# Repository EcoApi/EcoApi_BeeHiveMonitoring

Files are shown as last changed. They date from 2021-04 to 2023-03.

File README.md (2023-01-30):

# EcoApi Bee hive monitoring

description TBD

## Features

- External i2c sensor (ex: as6200, si7021, shtxx, ...)
- Microphone analog with max9814 (FFT with dma)
- Microphone i2s (FFT with dma)
- Weight with load scale using hx711 (opimized for 3.3V with noise filter), calibration by led information
- CPU STM32F411CEU6
- Motion detection using mercure tilt vibration sensor
- Internal i2c sensor (ex: bmp180, bme180, bme280, ...)
- Lora using rfm95w 
- Powered battery like : Li-ion, Li-po, 3xNimh, 4xNimh, LifePO4, Alkaline 3x1.5 / 2x1.5, Li-SOCL2, Li-Mn02, 18650
- Reverse battery protection
- USB charger
- Ultra low power in sleep mode (wakeup by external rtc) ~2µA
- Power in running mode TBD
- USB cdc from stm32
- Power switch for internal / external VCC (3.3V)
- Fram
- EEprom
- Flash SPI
- External nano watchdog
- Debug by led, Uart, 

## Hardware

### Characteristics

- Cpu
- Lora
- Consumption
- Fram
- EEprom
- Flash
- Rtc
- WDG
- HX711
- Protection battery
- Backup capacitor explanation
- Battery charger
- USB cdc
- Ldo
- Buck-boost
- Power Load switch
- Wakeup parts (button, wdg, motion, rtc)
- Dip switch
- Connector (load cell, external sensors, Battery, internal sensor, Debug & SWD)
- Push button
- Debug (Uart, USB CDC, SWD)
- ....

### Pcb

Front
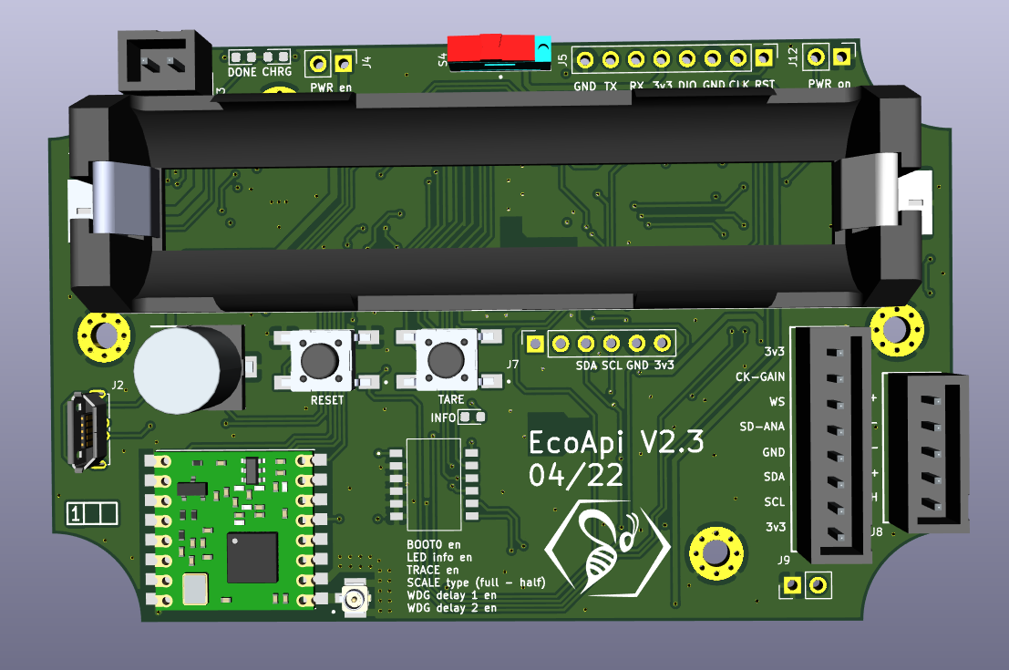
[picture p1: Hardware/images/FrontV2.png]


Back
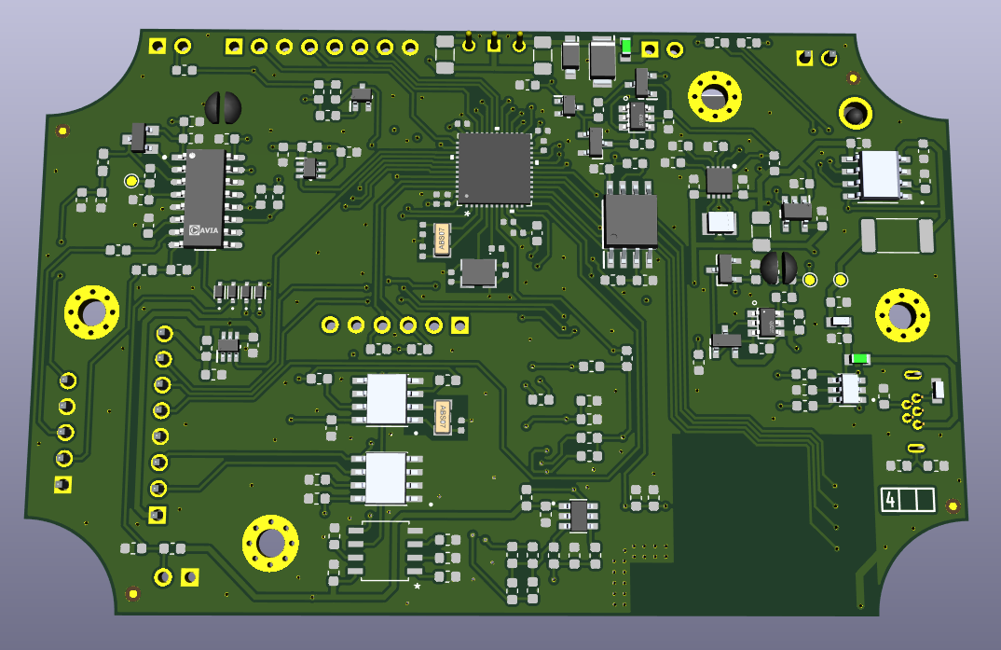
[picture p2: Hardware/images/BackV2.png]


### Pinout

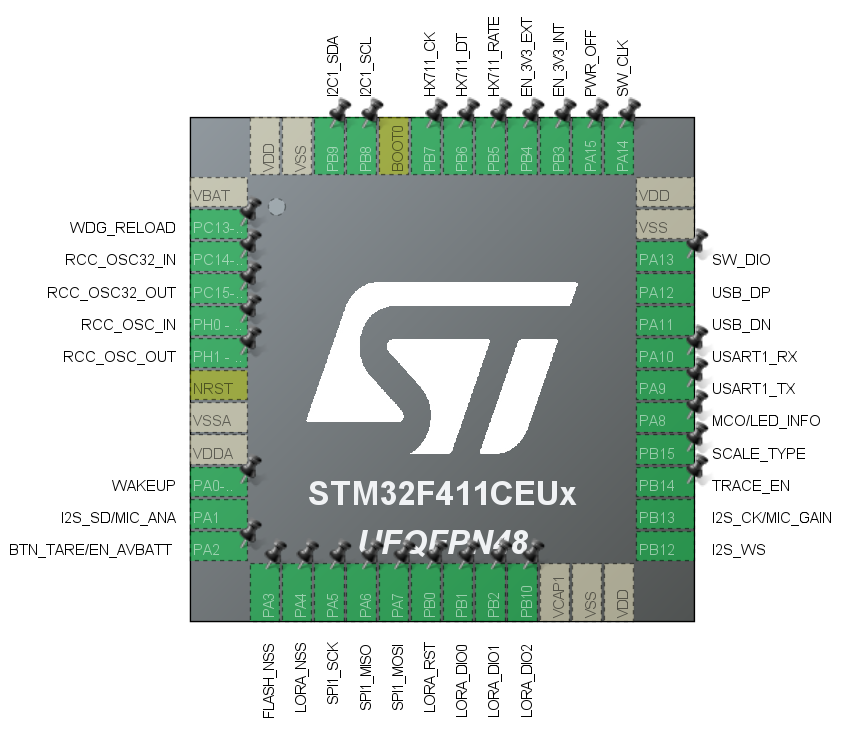
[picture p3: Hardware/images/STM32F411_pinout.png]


array of pins description

### pcb

describ options with 0R resistors. etc ...

#### JlcPcb production

- Bom and pick&place : https://support.jlcpcb.com/article/153-how-to-generate-bom-and-centroid-files-from-kicad-in-linux
- JlcPcb gerber files : https://support.jlcpcb.com/article/149-how-to-generate-gerber-and-drill-files-in-kicad

## Software

To be define (flow chart) ...

### Description

- Lora : ttn, webhook for beep, js decoder, frame format
- sensor template
- Sensors auto-detection
- Outside informations (temperature, pressure, humidity, wind, ...)
- Inside informations (Sound, temperature, humidity, gas, bee counter, custom sensor ...)
- System information (RSSI, VBATT, 
- describe directive in platforio.ini
- FFT on analog mic or I2S mic (parameters, range etc ...)
- sleep mode

### Ide & compilation

- pio
- plugins
- ....

### lmic debug ###

in platformio.ini

(1) uncomment :
	-D LMIC_DEBUG_LEVEL=2
	-D LMIC_ENABLE_event_logging=1
	-D LMIC_X_DEBUG_LEVEL=1

(2) replace in lmic/lmic.h :

#  ifdef LMIC_DEBUG_PRINTF_FN
#    define LMIC_X_DEBUG_PRINTF(f, ...) LMIC_DEBUG_PRINTF_FN(f, ## __VA_ARGS__)
#  else
#    error "LMIC_DEBUG_PRINTF_FN must be defined for LMIC_X_DEBUG_LEVEL > 0."
#  endif

by :

#define LMIC_X_DEBUG_PRINTF(f, ...) LMIC_DEBUG_PRINTF(f, ## __VA_ARGS__)

## how to

- Scale full or half
- Tare button
- Led information
- Motion tilt
- Debug
- usb charger leds
- Sleep on VBATT or 3.3V with slide switch
- Dip switch
- USB with android application (flutter.io or other)

## other 
[Editor.md](https://pandao.github.io/editor.md/en.html "Editor.md")

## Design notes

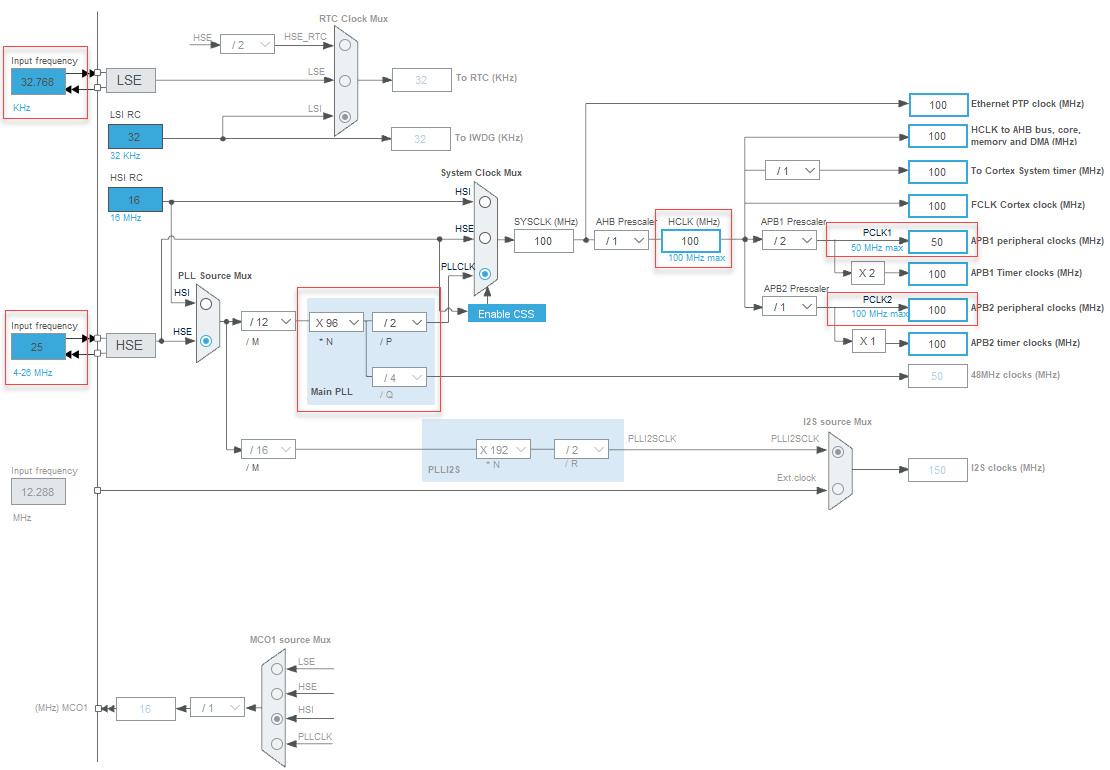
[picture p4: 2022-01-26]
Hardware/images/ide_hse_clock.png

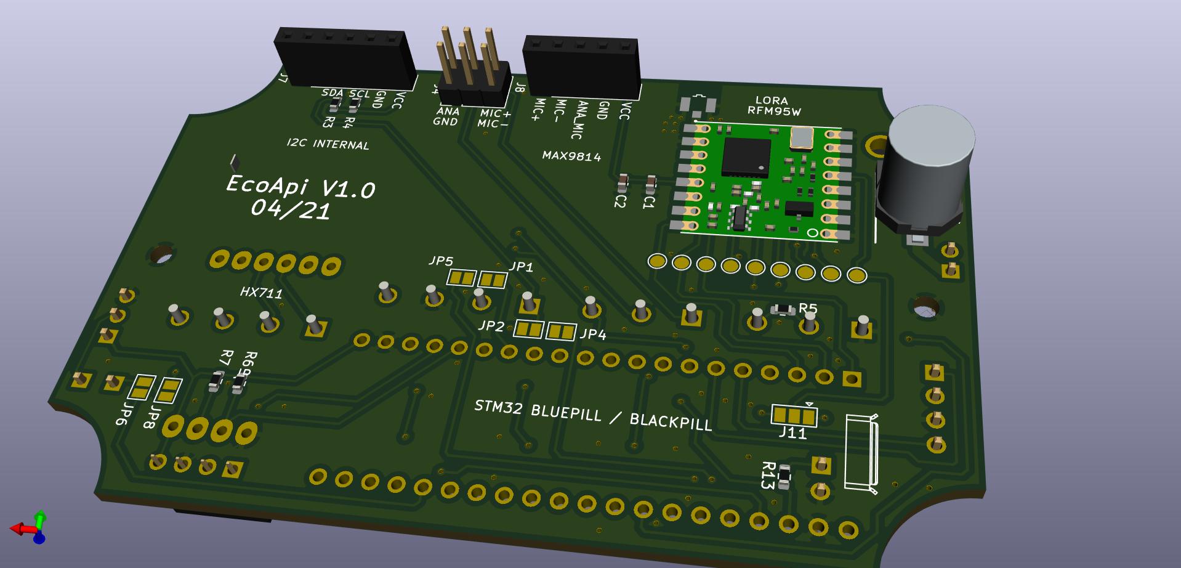
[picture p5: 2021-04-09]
Hardware/images/EcoApi_pcb3.jpg

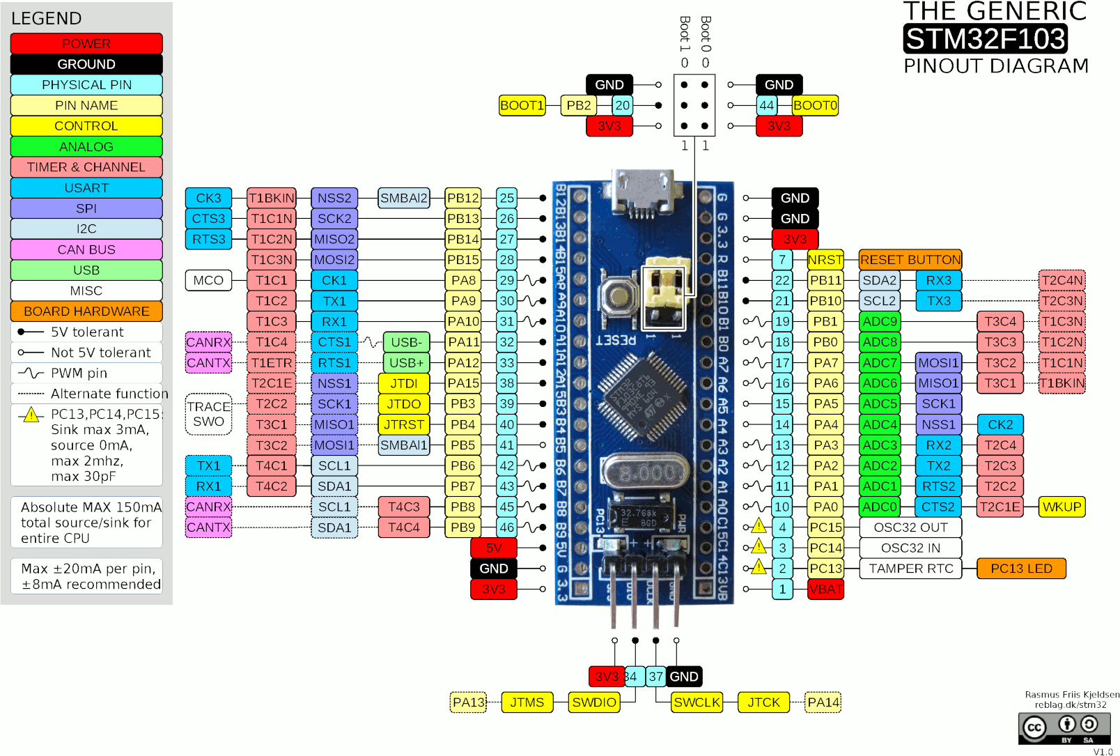
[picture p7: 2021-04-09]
Hardware/images/bluepill-pins.png

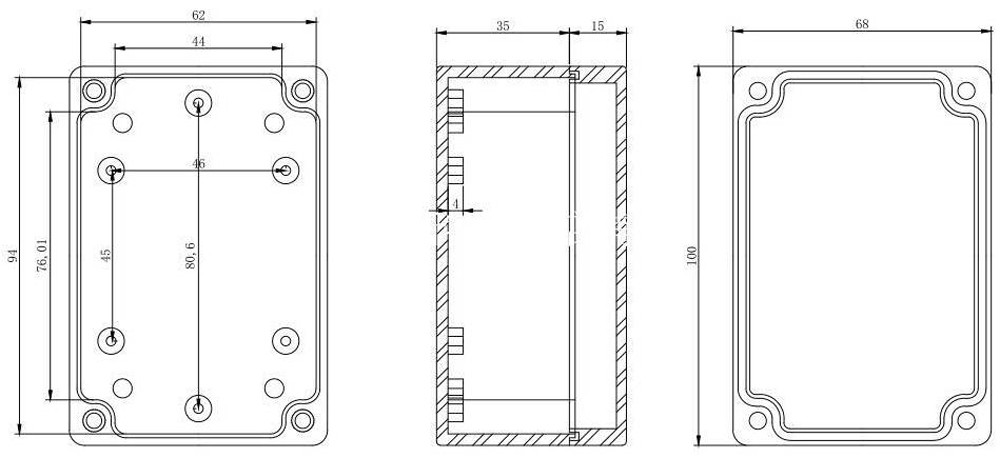
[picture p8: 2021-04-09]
Hardware/images/boitier.jpg

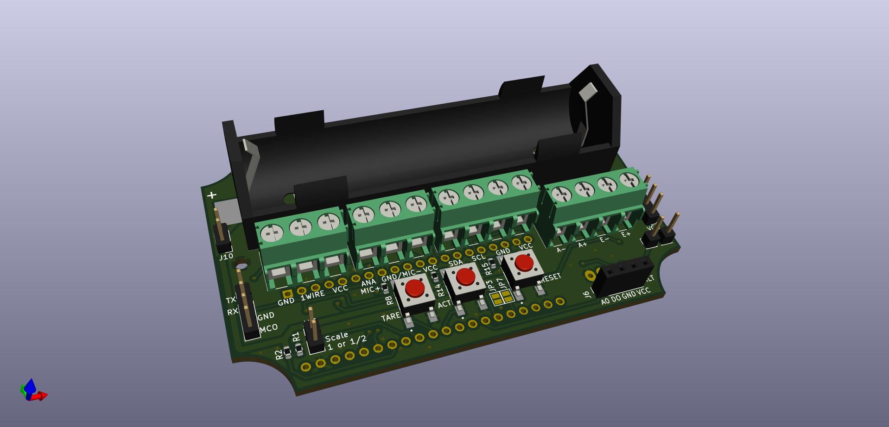
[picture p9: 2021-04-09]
Hardware/images/EcoApi_pcb2.jpg

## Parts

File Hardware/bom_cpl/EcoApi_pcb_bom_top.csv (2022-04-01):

Comment | Designator | Footprint | LCSC Part #
RFM95W-868S2 | U5
UFL | J1
1000uF | C18
POWER ON | J4 J12
18650_HOLDER | BT1
RED | D1
GREEN | D2
B2B-XH-A | J3
614105150721 | J2
I2C INTERNAL | J7
TARE | S1
RESET | S3
BLUE | D7
DSHP06TSGET | S2
B5B-XH-A__LF__SN_ | J8
B8B-XH-A_LF__SN_ | J9
TILT | J10
MSS-102559-14A-D | S4
Debug | J5

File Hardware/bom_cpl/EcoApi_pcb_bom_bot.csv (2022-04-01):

Comment | Designator | Footprint | LCSC Part #
0.1uF | C8 C7 C5 C6 C10 C11 C14 C15 C13 C2 C25 C22 C29 C44 C30 C31 C32 | 0603 | C1591
10uF | C9 C4 C12 C16 C21 | 0603 | C19702
4.7K | R26 R28 R29 R32 | 0603 | C23162
HX711 | U2 | SOP-16 | C43656
100R | R4 R5 | 0603 | C54021
20K | R22 | 0603 | C4184
22K | R21 | 0603 | C31850
3.3uH | L1 | 0603 | C21189
MB85RC04VPNF-G-JNERE1 | U4 | SOIC-8 | C8738
24LC02BT-I/SN | U7 | SOIC-8 | C5453
W25Q32JVSS | U6 | SOP-8 | C82344
0R | R20 R19 R18 R31 R8 R54 R55 R12 R13 R11 R25 | 0603 | NM_C21189
0R | R30 R33 R27 R24 R1 R17 R7 R49 R63 | 0603 | C21189
221K | R6 | 0603 | C22894
287K | R9 | 0603 | C22972
182K | R2 | 0603 | C22894
187K | R3 | 0603 | C22896
MMBT4403 | Q1 | SOT-23-3 | C85183
PCF8563T_5,518 | IC1 | SOIC-8 | C7440
TPL5010DDCR | U1 | SOT-23-6 | C473912
32.768kHz 12.5pF | Y1 | 3215 | C97606
22pF | C1 | 0402 | C76960
10K | R16 R58 R39 R68 R73 R67 R71 R69 | 0603 | C25804
TPS63900DSKR | U10
10uF | C23 | 0603 | NM_C19702
22uF | C24 | 0603 | NM_C59461
36.5K | R52 | 0603 | NM_C51261_
TP4056X | U8 | SOP-8 | C2763448
1K | R37 R36 R72 | 0603 | C21190
0.5R | R35 | 2512 | C27777
100K | R50 R44 R38 R23 | 0603 | C25803
IRLML6244TRPBF | Q3 Q6 | SOT-23-3 | C143946
1M | R47 R48 R53 R34 R51 R65 R42 R15 R45 | 0603 | C22935
10nF | C19 C46 | 0603 | C100042
4.7uF | C20 C17 | 0603 | C19666
22R | R40 R41 | 0603 | C23345
BLM18PG221SN1D | FB2 FB1 | 0603 | C80165
MF-FSMF050X-2 | F1 F2 | 0603 | C210357
FDC638P | Q2 Q7 | SSOT-6
1N4148WT | D6 D4 D5 D3 | SOD-523 | C232841
2.2uH | L2 | 0603
SIP32431DR3-T1GE3 | IC2 IC3 | SC-70-6 | C141606
BSS138 | Q5 Q4 | SOT-323-3 | C24553
USBLC6-2SC6 | D8 | SOT-23-6 | C7519
1uF | C26 C28 C27 C45 | 0603 | C59782
0R | R10 R46 R56 | 1206 | NM_C17888
NCP161ASN330T1G | PS1 | SOT-23-5 | C892187
BSS84AK,215 | Q8 Q9 | SOT-23-3 | C127273
PMEG10020AELPX | D10 | SOD-128 | C503397
PMEG10010ELRX | D9 | SOD-123W | C179426
4.7uF | C39 C40 | 0402 | C77004
STM32F411CEU6 | U13 | UFQFPN-48 | C60420
0.1uF | C41 C42 C43 C38 | 0402 | C1525
1uF | C37 | 0402 | C307427
25mHz 9pF +-10ppm | Y3 | 3225 | C255920
8pF | C35 C36 | 0402 | C161335
787R | R75 | 0402 | C270582
32.768kHz 6pF | Y2 | 3215 | C2692145
6pF | C34 C33 | 0402 | C437443
600Ω@100MHz | L3 | 0603 | C133937

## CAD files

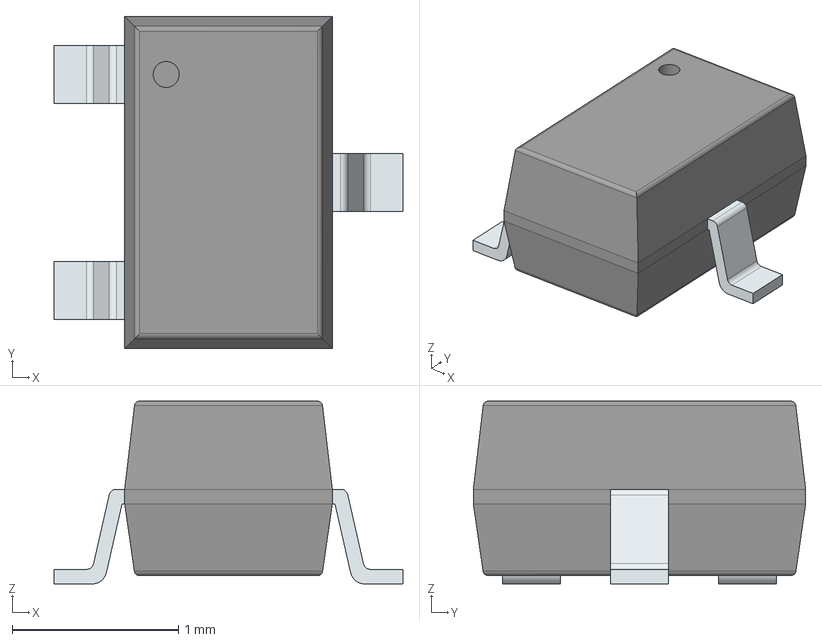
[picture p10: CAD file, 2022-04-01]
Hardware/lib_3d/BSS138PW,115.stp
2.10 x 2.00 x 1.10 mm
PinsArrayL
FilletPinR

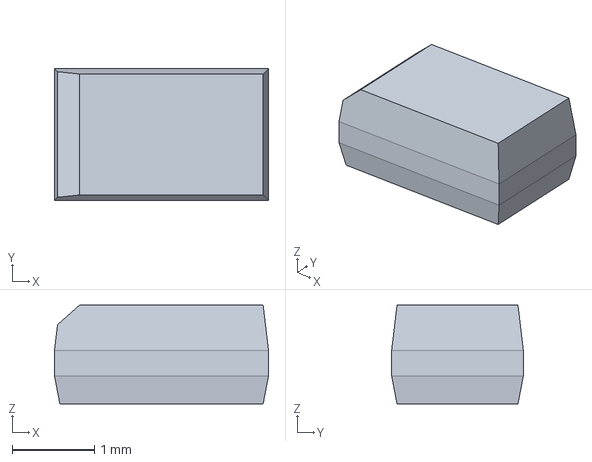
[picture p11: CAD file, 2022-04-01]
Hardware/lib_3d/BAT46WH,115.stp
2.60 x 1.60 x 1.20 mm

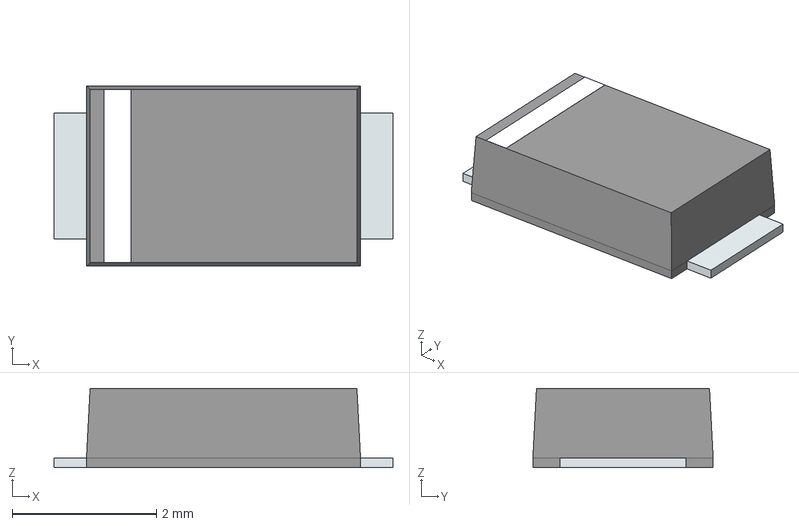
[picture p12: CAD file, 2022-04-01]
Hardware/lib_3d/PMEG10020AELPX.stp
4.70 x 2.50 x 1.10 mm
PinKIdent
PinK
PinA

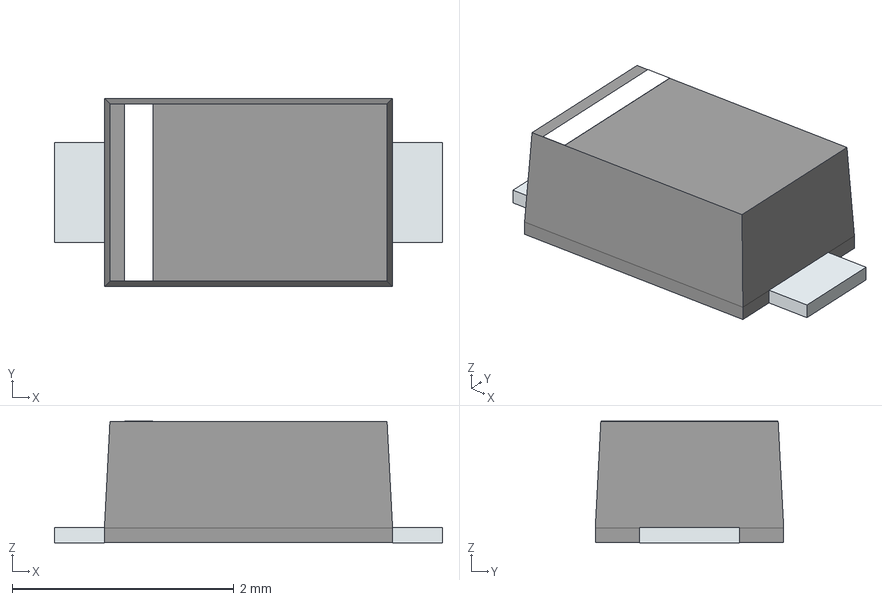
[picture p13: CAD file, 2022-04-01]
Hardware/lib_3d/PMEG10010ELRX.stp
3.50 x 1.70 x 1.10 mm
PinKIdent
PinK
PinA

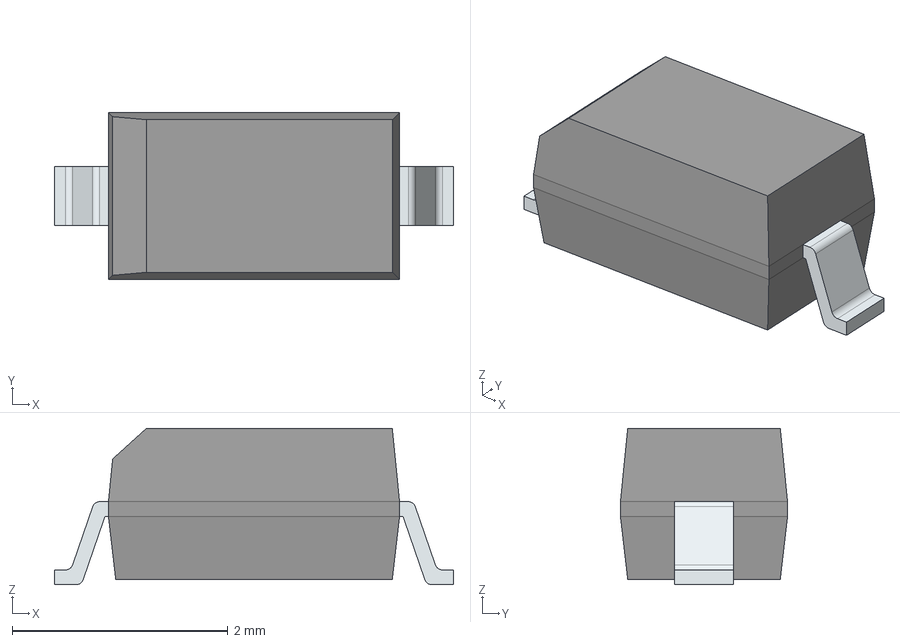
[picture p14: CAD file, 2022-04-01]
Hardware/lib_3d/BAT46W-7-F.stp
3.70 x 1.55 x 1.45 mm
FilletPinL
FilletPinR

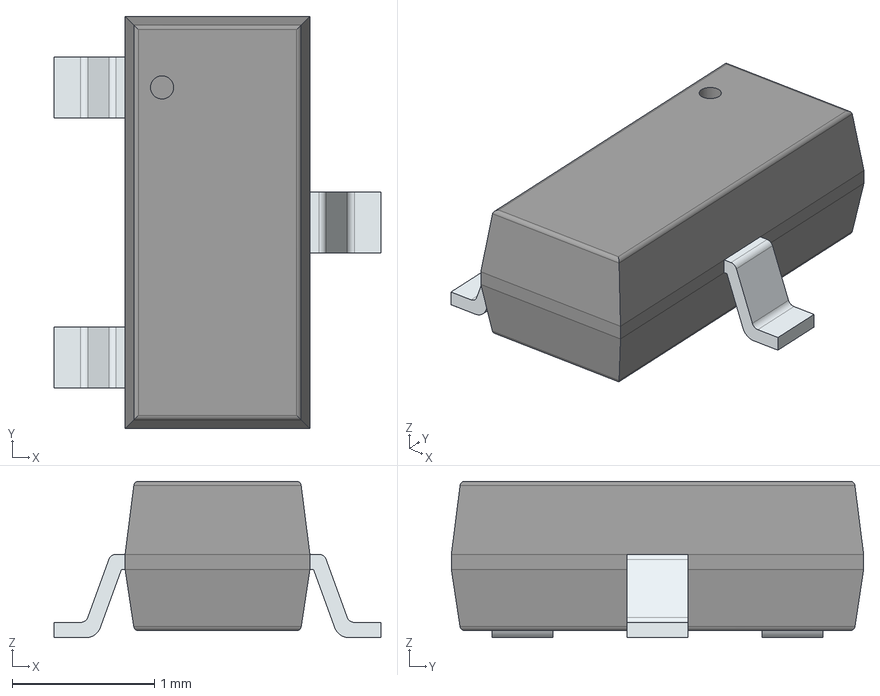
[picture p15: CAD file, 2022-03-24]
Hardware/lib_3d/BSS84AK,215.stp
2.30 x 2.90 x 1.10 mm
PinsArrayL
FilletPinR

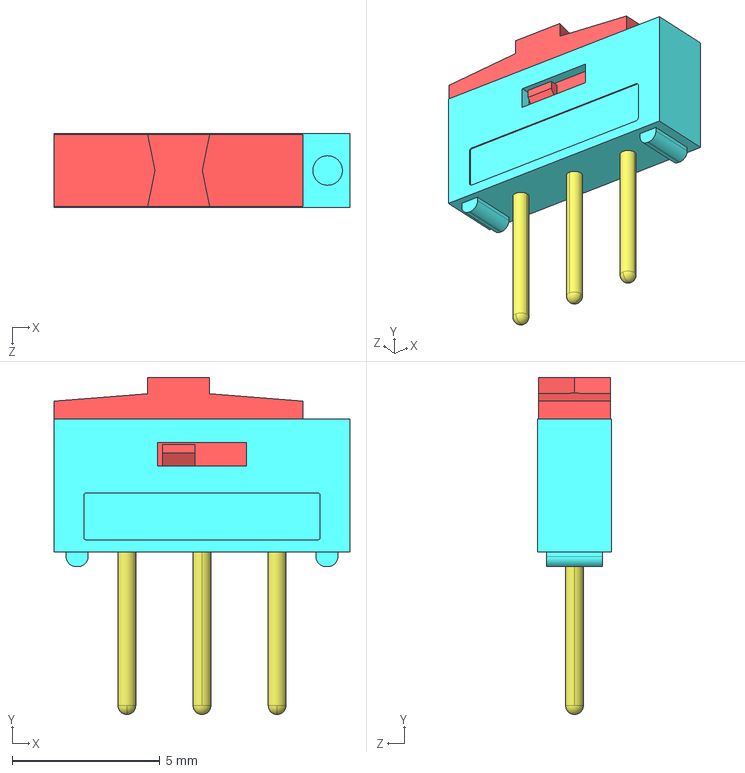
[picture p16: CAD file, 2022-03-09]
Hardware/lib_3d/MSS-102559-14A-D.step
10.0 x 11.4 x 2.50 mm

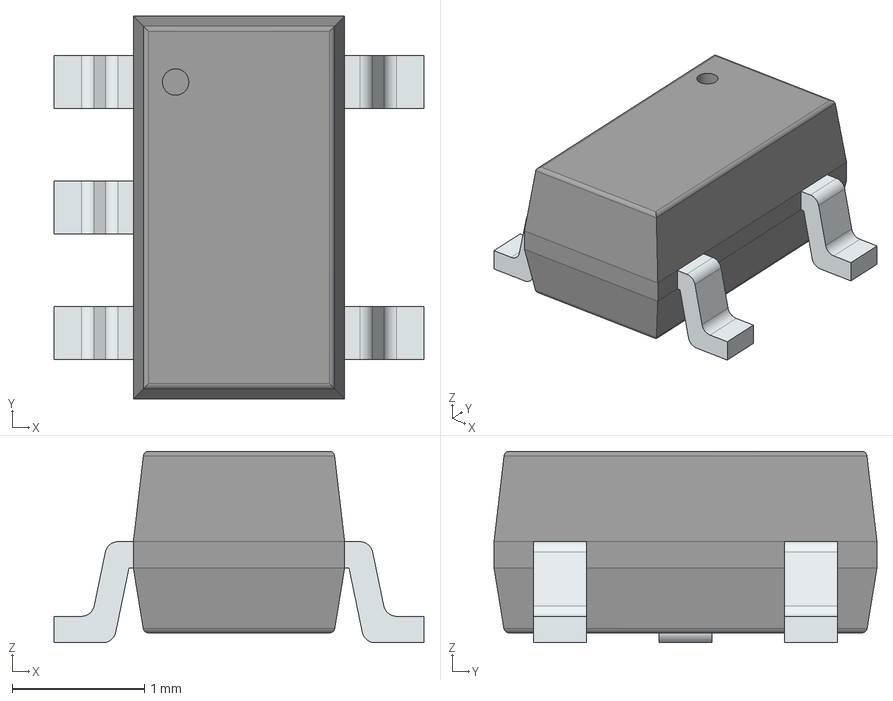
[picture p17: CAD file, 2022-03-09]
Hardware/lib_3d/NCP161ASN330T1G.stp
2.80 x 2.90 x 1.45 mm
PinsArrayL
PinsArrayR

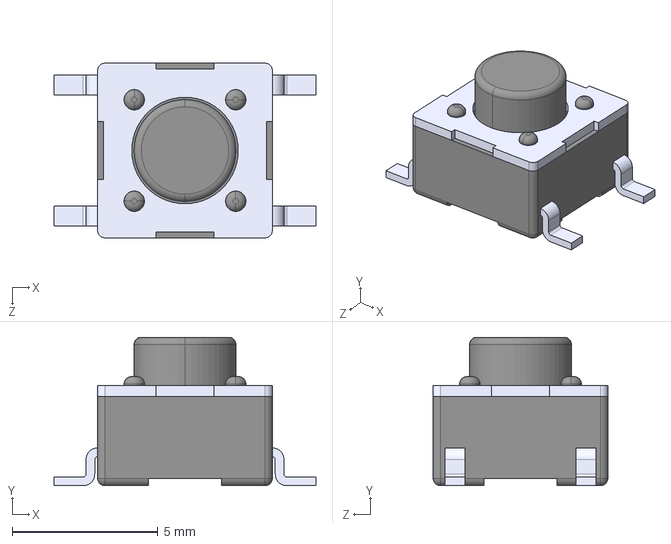
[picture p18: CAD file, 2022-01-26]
Hardware/lib_3d/PTS645SK50SMTR92LFS.STEP
9.00 x 5.10 x 6.00 mm

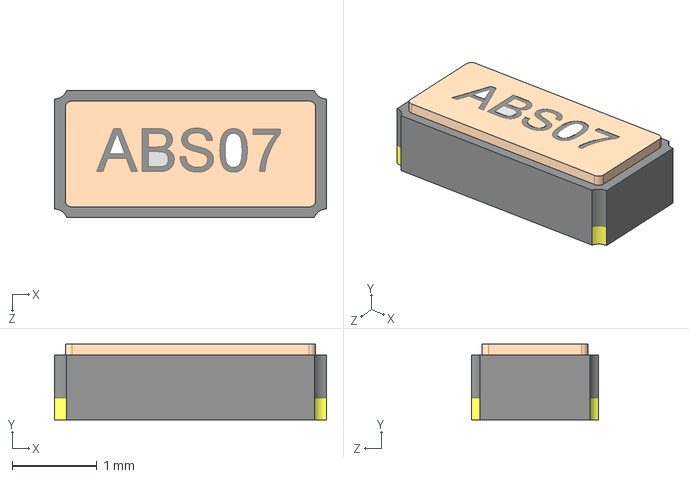
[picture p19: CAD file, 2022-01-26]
Hardware/lib_3d/ABS07-120-32.768KHZ-T.step
3.20 x 0.889 x 1.50 mm

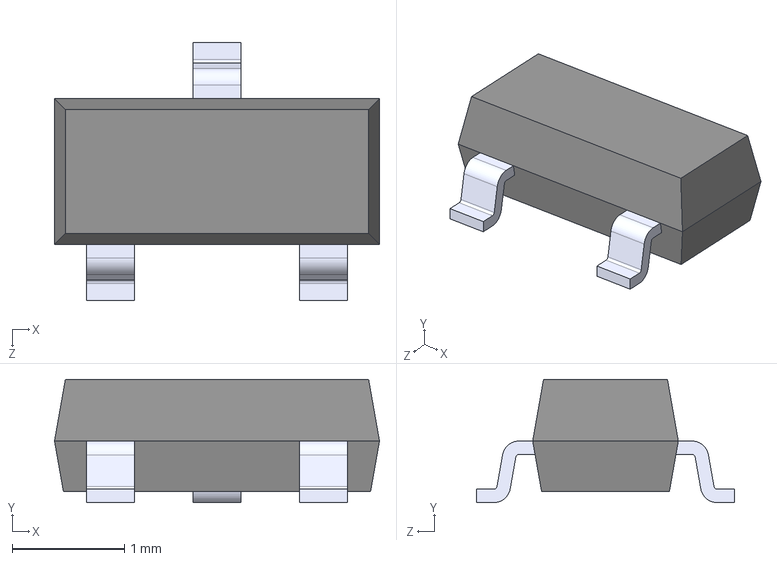
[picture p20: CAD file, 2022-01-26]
Hardware/lib_3d/BSS138.step
2.90 x 1.10 x 2.30 mm

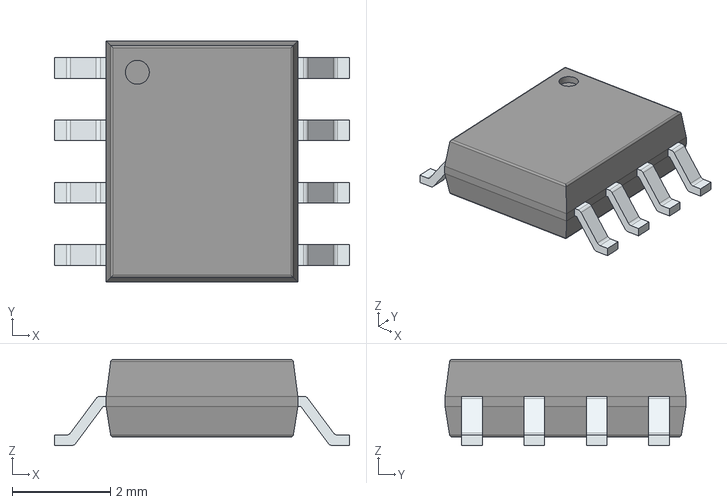
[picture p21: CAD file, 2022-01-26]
Hardware/lib_3d/PCF8563T_5,518.stp
6.00 x 4.90 x 1.75 mm
PinsArrayLR

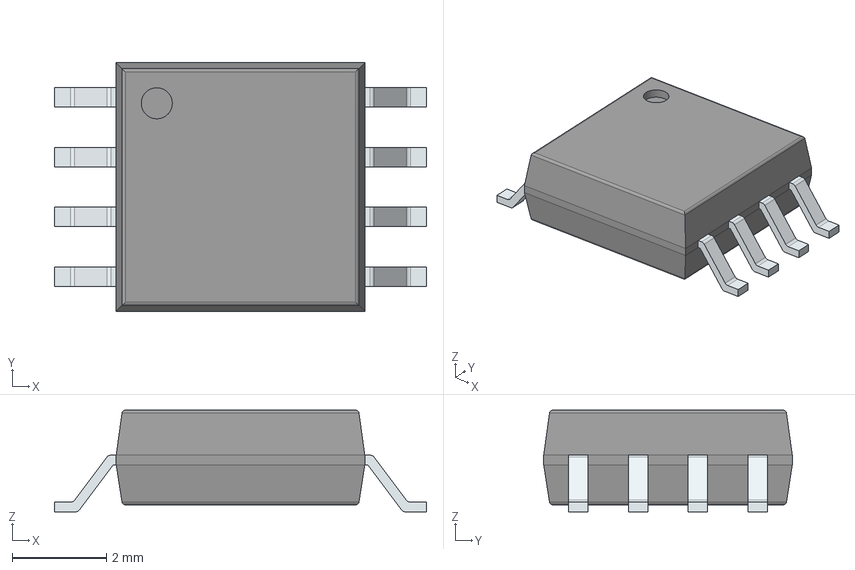
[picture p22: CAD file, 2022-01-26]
Hardware/lib_3d/W25Q32JVSSIQ_TR.stp
7.90 x 5.28 x 2.16 mm
PinsArrayLR

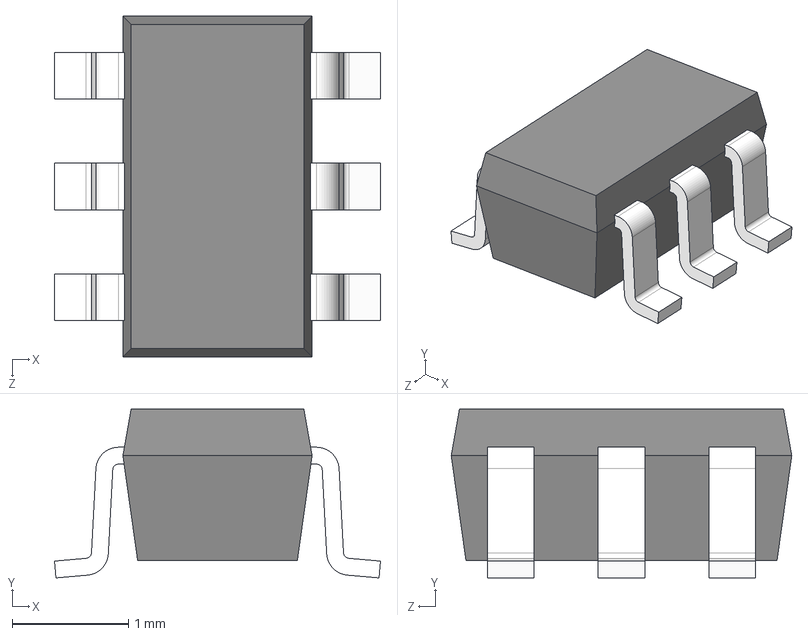
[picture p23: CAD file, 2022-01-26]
Hardware/lib_3d/USBLC6-2SC6.step
2.80 x 1.45 x 2.92 mm

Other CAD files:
Hardware/lib_3d/MMBT4403_.step
Hardware/lib_3d/BLM18PG221SN1D.step
Hardware/lib_3d/1042.step
Hardware/lib_3d/IRLML6244TRPBF.stp
Hardware/V1/lib_3d/EEE-FK0J102GP.stp
Hardware/V1/lib_3d/HX711.STEP
Hardware/V1/lib_3d/RFM9xW.step
Hardware/V1/lib_3d/U.FL-R-SMT_01_.step
Hardware/V1/lib_3d/UCD0J102MNL1GS.stp
Hardware/lib_3d/1N4148WT.step
Hardware/lib_3d/24LC02B_SN.step
Hardware/lib_3d/614105150721.stp
Hardware/lib_3d/Avia_Semiconductor_-_HX711.step
Hardware/lib_3d/B2B-XH-A.stp
Hardware/lib_3d/B5B-XH-A__LF__SN_.stp
Hardware/lib_3d/B8B-XH-A_LF__SN_.stp
Hardware/lib_3d/BLM18PG221SN1D.stp
Hardware/lib_3d/DFE252012P-2R2M_P2.step
Hardware/lib_3d/EEE-FK0J102GP.stp
Hardware/lib_3d/Fairchild_-_MMBT4403.step
Hardware/lib_3d/HX711.STEP
Hardware/lib_3d/IRLML6246TRPBF.step
Hardware/lib_3d/MF-FSMF050X-2.step
Hardware/lib_3d/MF-FSMF050X-2.stp
Hardware/lib_3d/ON_Semiconductor_-_FDC638P.step
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

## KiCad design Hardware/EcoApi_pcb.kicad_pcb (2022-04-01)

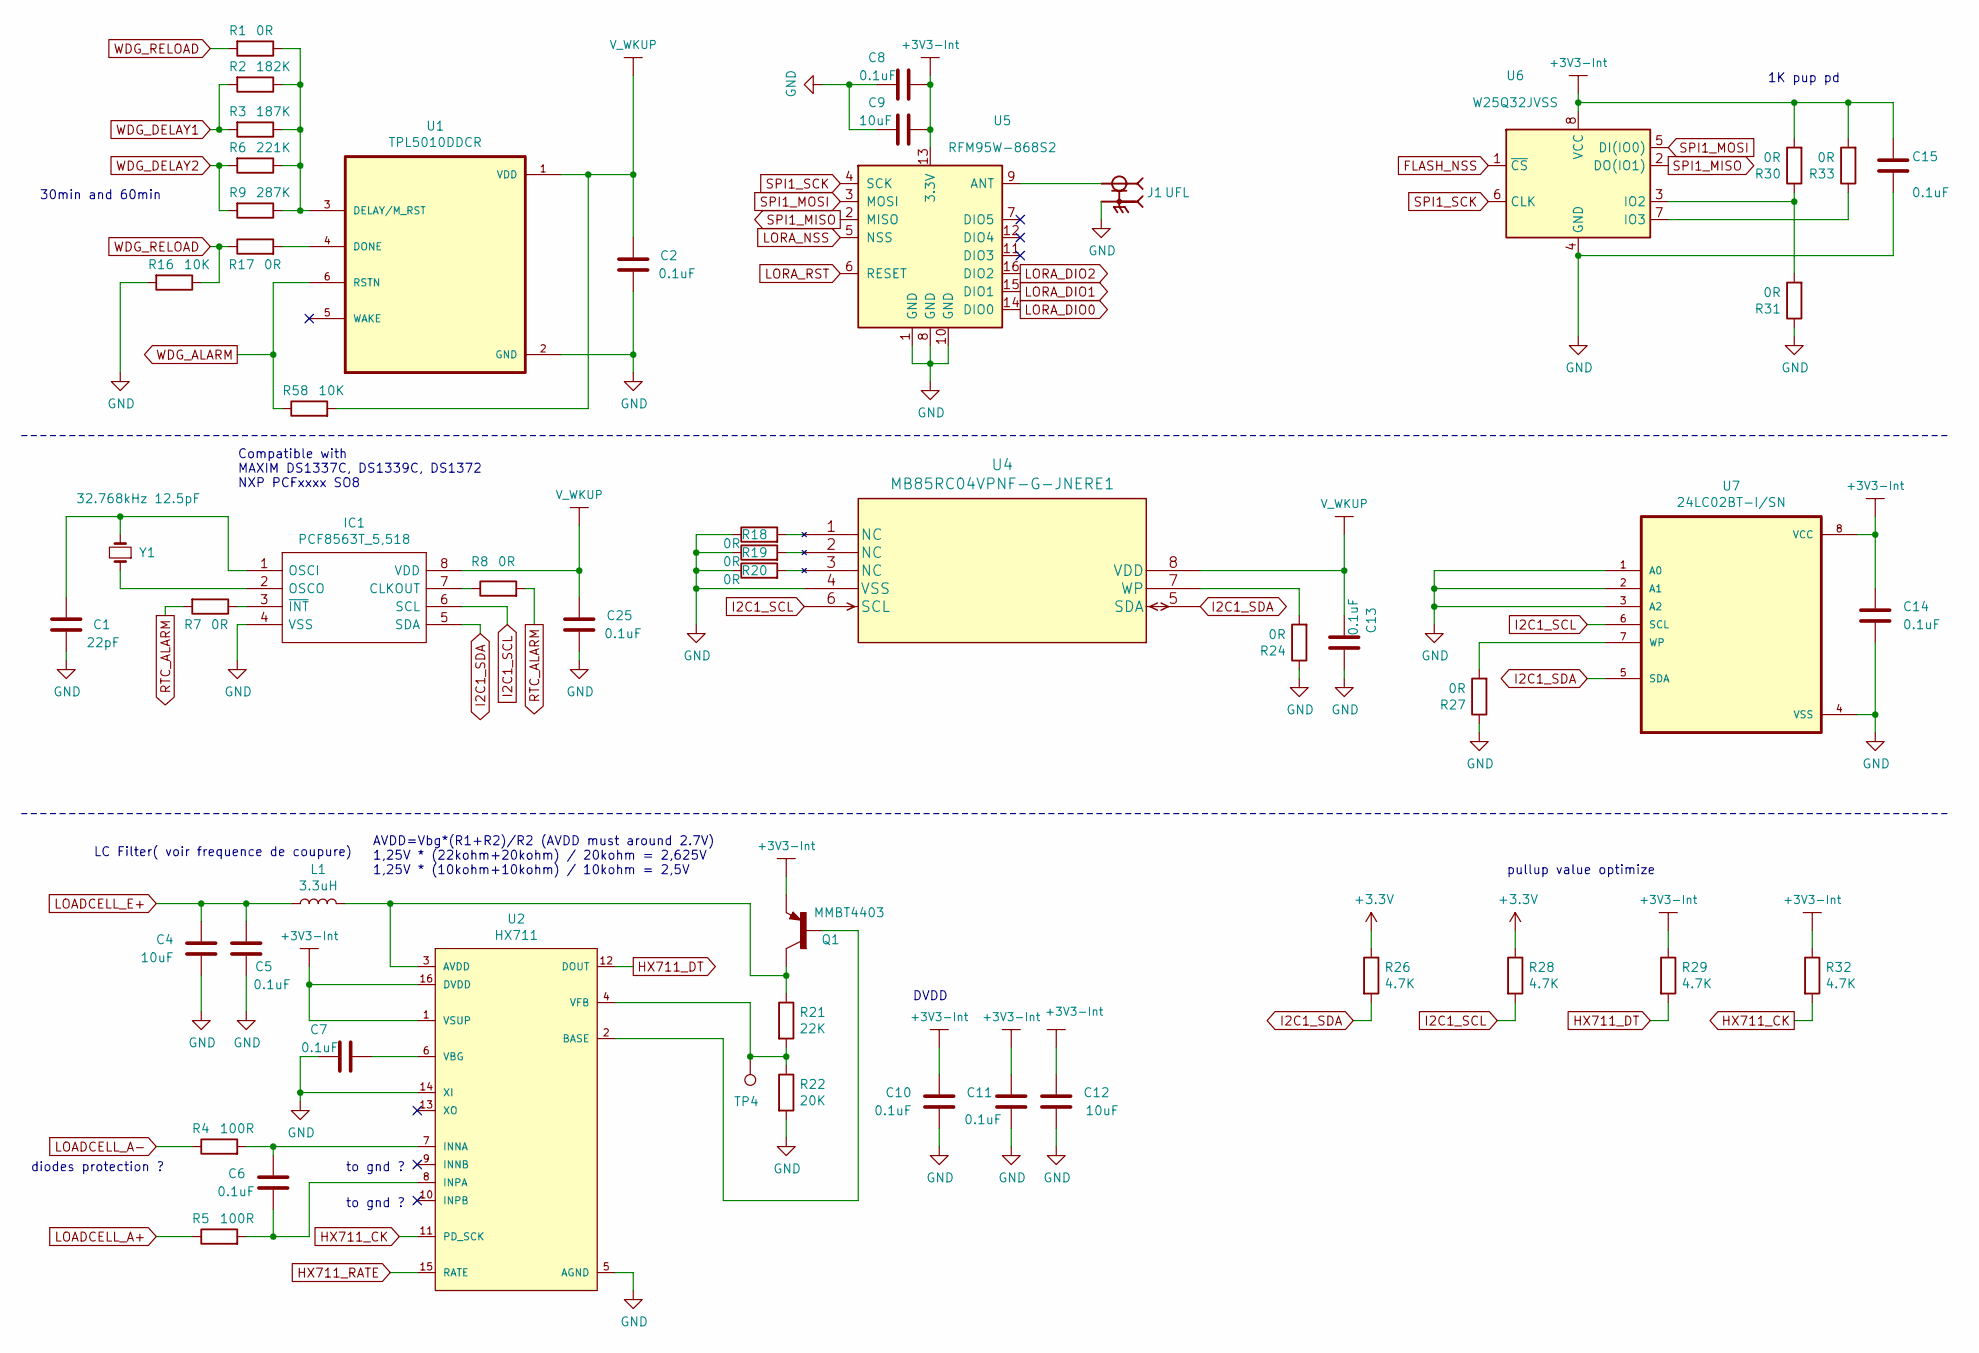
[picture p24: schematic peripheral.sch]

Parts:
C1: 22pF; C_0402_1005Metric; Tolerance 5%; Voltage 50V; Manufacturer_Part_Number GRM1555C1H220JA01D; JLC 0402
C2, C5, C6, C7, C8, C11, C13, C14, C15, C25: 0.1uF; C_0603_1608Metric; Tolerance 10%; Voltage 50V; Manufacturer_Part_Number CL10B104KB8NNNC; JLC 0603
C4: 10uF; C_0603_1608Metric; Voltage 10V; Tolerance 10%; Manufacturer_Part_Number CL10A106KP8NNNC; JLC 0603
C9, C12: 10uF; C_0603_1608Metric; Tolerance 10%; Voltage 10V; Manufacturer_Part_Number CL10A106KP8NNNC; JLC 0603
C10: 0.1uF; C_0603_1608Metric; Voltage 50V; Tolerance 10%; Manufacturer_Part_Number CL10B104KB8NNNC; JLC 0603
IC1: PCF8563T_5,518; SOIC127P600X175-8N; Manufacturer_Part_Number PCF8563T/5,518; Mouser Part Number 771-PCF8563T/5518
J1: UFL; IPEX_20279-001E-01; PARTREV 21
L1: 3.3uH; L_0603_1608Metric_Pad1.05x0.95mm_HandSolder; Manufacturer_Part_Number 0603WAF0000T5E; JLC 0603
Q1: MMBT4403; SOT23-BEC; Manufacturer_Part_Number MMBT4403-7-F; JLC SOT-23-3
R1, R7, R8, R17, R18, R19, R20, R24, R27, R30, R31, R33: 0R; R_0603_1608Metric; Tolerance 1%; Power Rating 1/10W; Manufacturer_Part_Number 0603WAF0000T5E; JLC 0603
R2: 182K; R_0603_1608Metric; Tolerance 1%; Power Rating 1/10W; Manufacturer_Part_Number 0603WAF1823T5E; JLC 0603
R3: 187K; R_0603_1608Metric; Tolerance 1%; Power Rating 1/10W; Manufacturer_Part_Number 0603WAF1873T5E; JLC 0603
R4, R5: 100R; R_0603_1608Metric; Tolerance 0.1%; Power Rating 1/16W; Manufacturer_Part_Number TC0325B1000T5E; JLC 0603
R6: 221K; R_0603_1608Metric; Tolerance 1%; Power Rating 1/10W; Manufacturer_Part_Number 0603WAF1823T5E; JLC 0603
R9: 287K; R_0603_1608Metric; Tolerance 1%; Power Rating 1/10W; Manufacturer_Part_Number 0603WAF2873T5E; JLC 0603
R16, R58: 10K; R_0603_1608Metric; Tolerance 1%; Power Rating 1/10W; Manufacturer_Part_Number 0603WAF1002T5E; JLC 0603
R21: 22K; R_0603_1608Metric; Tolerance 1%; Power Rating 1/10W; Manufacturer_Part_Number 0603WAF2202T5E; JLC 0603
R22: 20K; R_0603_1608Metric; Tolerance 1%; Power Rating 1/10W; Manufacturer_Part_Number 0603WAF2002T5E; JLC 0603
R26, R28, R29, R32: 4.7K; R_0603_1608Metric; Tolerance 1%; Power Rating 1/10W; Manufacturer_Part_Number 0603WAF4701T5E; JLC 0603
TP4: TestPoint; TestPoint_Pad_D1.0mm
U1: TPL5010DDCR; SOT95P280X110-6N; Manufacturer_Part_Number TPL5010DDCR; JLC SOT-23-6
U2: HX711; Avia_Semiconductor-HX711-IPC_A; Manufacturer_Part_Number HX711Copy; JLC SOP-16
U4: MB85RC04VPNF-G-JNERE1; MB85RC16PNF-G-JNE1; Manufacturer_Part_Number MB85RC04VPNF-G-JNERE1; JLC SOIC-8
U5: RFM95W-868S2; RFM95W
U6: W25Q32JVSS; SOIC127P790X216-8N; Manufacturer_Part_Number W25Q32JVSSIQ; JLC SOP-8
U7: 24LC02BT-I/SN; SOIC127P600X175-8N; Manufacturer_Part_Number 24LC02BT-I/SN; JLC SOIC-8
Y1: 32.768kHz 12.5pF; XTAL_ABS07-120-32.768KHZ-T; Manufacturer_Part_Number SC-32S32.768kHz20PPM12.5pF; JLC 3215

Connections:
+3V3_int: C8.1, C9.1, C10.1, C11.1, C12.1, C14.2, C15.2, Q1.E, R29.1, R30.2, R32.1, R33.2, U2.1 (VSUP), U2.16 (DVDD), U5.13 (3.3V), U6.8 (VCC), U7.8 (VCC); also elsewhere on the board
FLASH_NSS: U6.1 (~CS); also elsewhere on the board
GND: C1.2, C2.2, C4.2, C5.2, C7.2, C8.2, C9.2, C10.2, C11.2, C12.2, C13.1, C14.1, C15.1, C25.2, IC1.4 (VSS), J1.2, J1.3, R16.2, R18.1, R19.1, R20.1, R22.2, R24.1, R27.1, R31.1, U1.2 (GND), U2.5 (AGND), U2.14 (XI), U4.4 (VSS), U5.1 (GND), U5.8 (GND), U5.10 (GND), U6.4 (GND), U7.1 (A0), U7.2 (A1), U7.3 (A2), U7.4 (VSS); also elsewhere on the board
HX711_CK: R32.2, U2.11 (PD_SCK); also elsewhere on the board
HX711_DT: R29.2, U2.12 (DOUT); also elsewhere on the board
HX711_RATE: U2.15 (RATE); also elsewhere on the board
I2C1_SCL: IC1.6 (SCL), R28.2, U4.6 (SCL), U7.6 (SCL); also elsewhere on the board
I2C1_SDA: IC1.5 (SDA), R26.2, U4.5 (SDA), U7.5 (SDA); also elsewhere on the board
LOADCELL_A+: R5.1; also elsewhere on the board
LOADCELL_A-: R4.1; also elsewhere on the board
LOADCELL_E+: C4.1, C5.1, L1.1; also elsewhere on the board
LORA_DIO0: U5.14 (DIO0); also elsewhere on the board
LORA_DIO1: U5.15 (DIO1); also elsewhere on the board
LORA_DIO2: U5.16 (DIO2); also elsewhere on the board
LORA_NSS: U5.5 (NSS); also elsewhere on the board
LORA_RST: U5.6 (RESET); also elsewhere on the board
unnamed: C1.1, IC1.1 (OSCI), Y1.2
unnamed: C6.1, R4.2, U2.7 (INNA)
unnamed: C6.2, R5.2, U2.8 (INPA)
unnamed: C7.1, U2.6 (VBG)
unnamed: IC1.2 (OSCO), Y1.1
unnamed: IC1.3 (~INT), R7.1
unnamed: IC1.7 (CLKOUT), R8.1
unnamed: J1.1, U5.9 (ANT)
unnamed: L1.2, Q1.C, R21.1, U2.3 (AVDD)
unnamed: Q1.B, U2.2 (BASE)
unnamed: R1.1, R2.1, R3.1, R6.1, R9.1, U1.3 (DELAY/M_RST)
unnamed: R17.2, U1.4 (DONE)
unnamed: R18.2, U4.1 (NC)
unnamed: R19.2, U4.2 (NC)
unnamed: R20.2, U4.3 (NC)
unnamed: R21.2, R22.1, TP4.1, U2.4 (VFB)
unnamed: R24.2, U4.7 (WP)
unnamed: R27.2, U7.7 (WP)
unnamed: R30.1, R31.2, U6.3 (IO2)
unnamed: R33.1, U6.7 (IO3)
RTC_ALARM: R7.2, R8.2; also elsewhere on the board
SPI1_MISO: U5.2 (MISO), U6.2 (DO(IO1)); also elsewhere on the board
SPI1_MOSI: U5.3 (MOSI), U6.5 (DI(IO0)); also elsewhere on the board
SPI1_SCK: U5.4 (SCK), U6.6 (CLK); also elsewhere on the board
V_WKUP: C2.1, C13.2, C25.1, IC1.8 (VDD), R58.2, U1.1 (VDD), U4.8 (VDD); also elsewhere on the board
WDG_ALARM: R58.1, U1.6 (RSTN); also elsewhere on the board
WDG_DELAY1: R2.2, R3.2; also elsewhere on the board
WDG_DELAY2: R6.2, R9.2; also elsewhere on the board
WDG_RELOAD: R1.2, R16.1, R17.1; also elsewhere on the board

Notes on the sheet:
AVDD=Vbg*(R1+R2)/R2 (AVDD must around 2.7V) 1,25V * (22kohm+20kohm) / 20kohm = 2,625V 1,25V * (10kohm+10kohm) / 10kohm = 2,5V
diodes protection ?
DVDD
to gnd ?
LC Filter( voir frequence de coupure)
Compatible with MAXIM DS1337C, DS1339C, DS1372 NXP PCFxxxx SO8
30min and 60min
pullup value optimize
1K pup pd

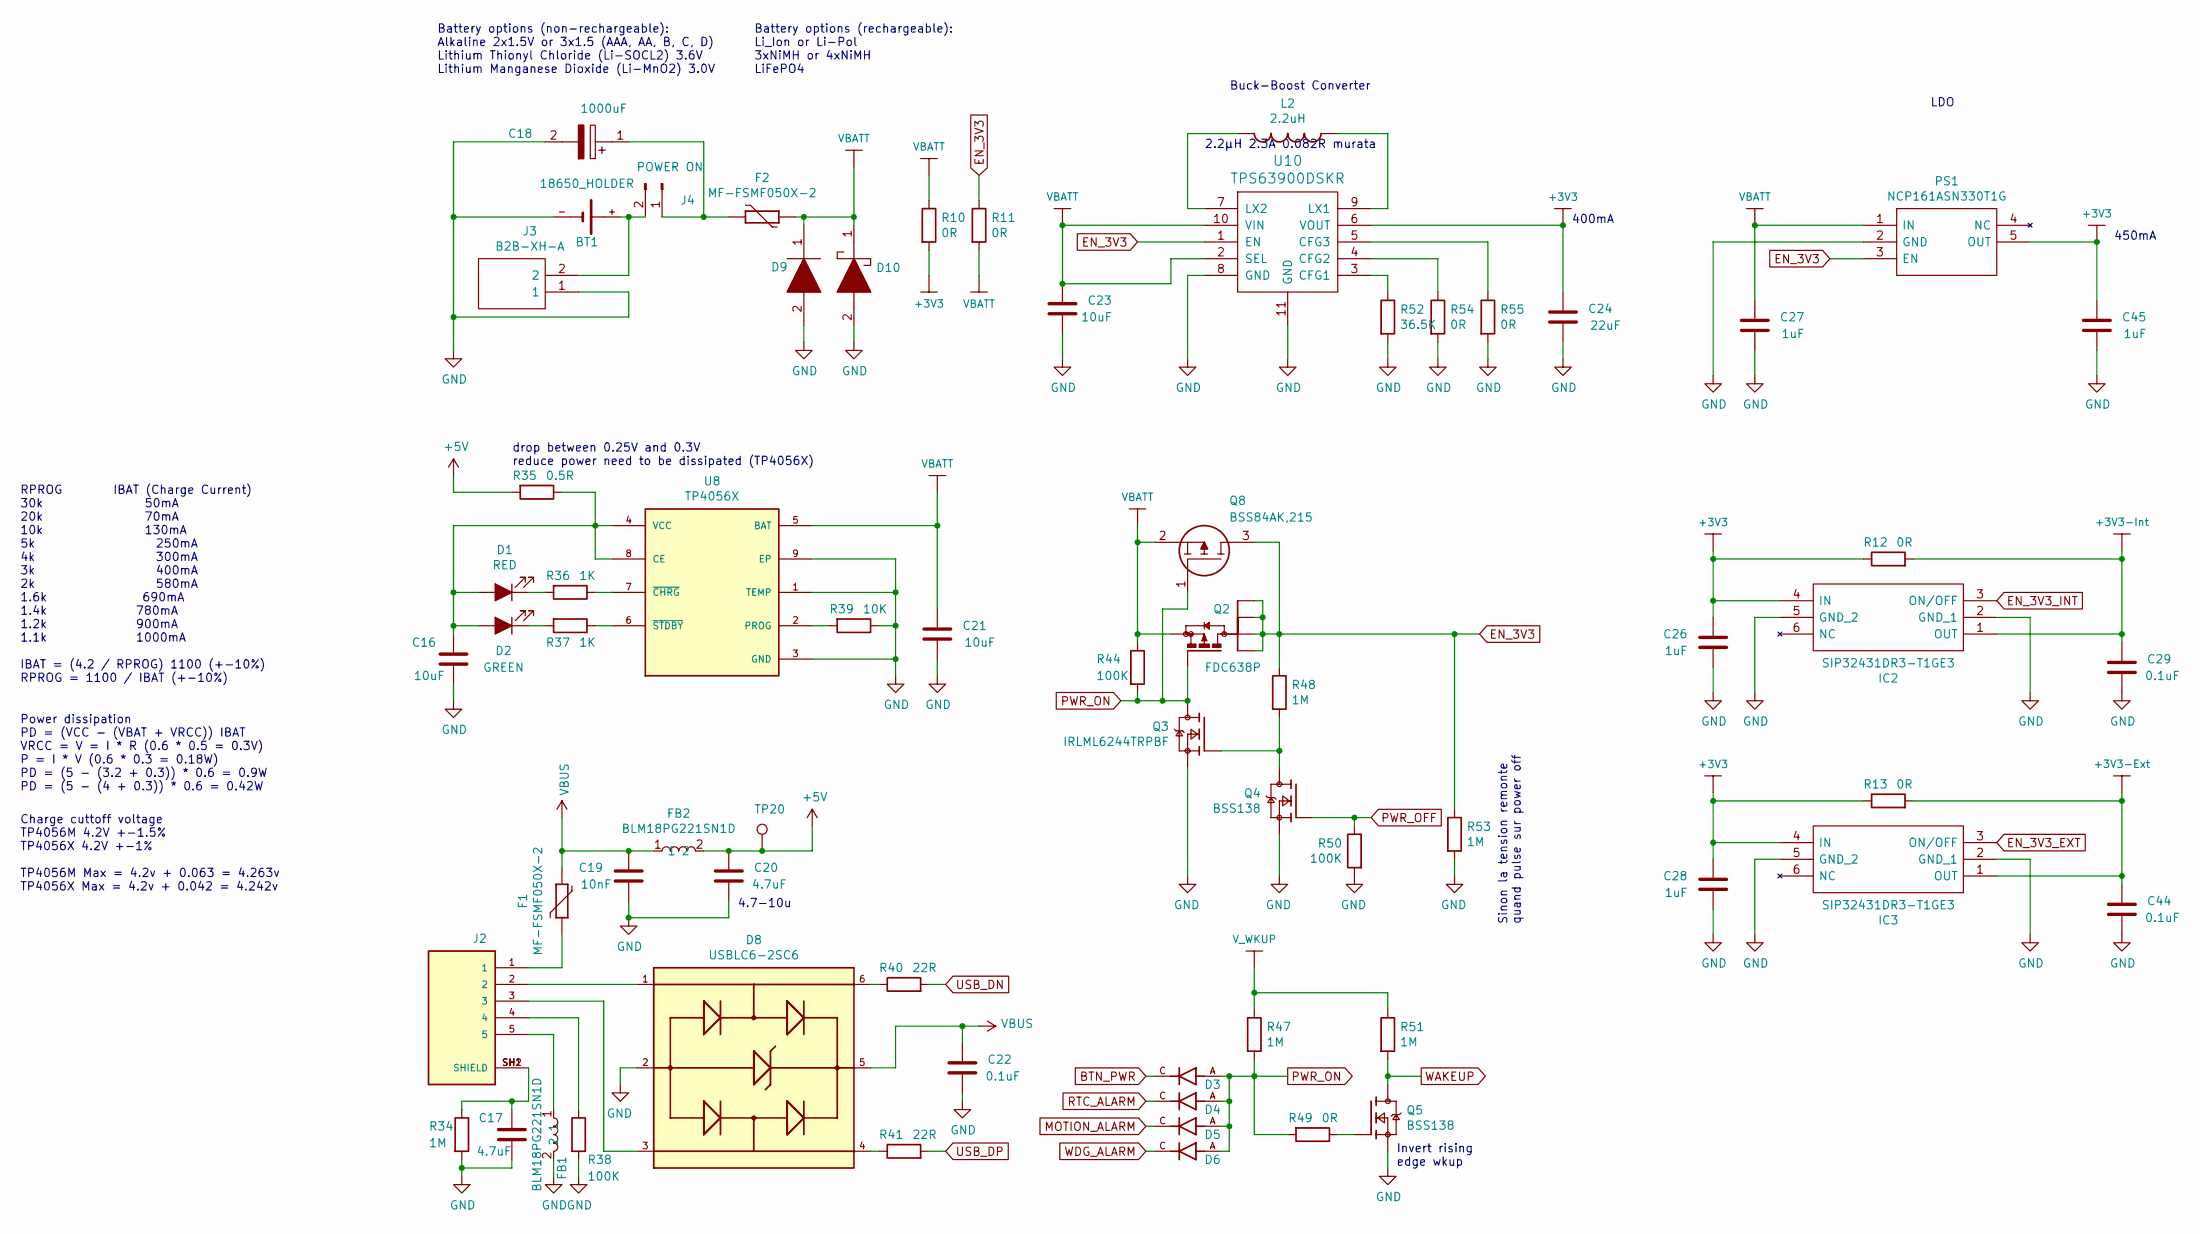
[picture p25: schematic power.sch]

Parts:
BT1: 18650_HOLDER; BAT_1042
C16, C21: 10uF; C_0603_1608Metric; Tolerance 10%; Voltage 10V; Manufacturer_Part_Number CL10A106KP8NNNC; JLC 0603
C17, C20: 4.7uF; C_0603_1608Metric; Tolerance 10%; Voltage 16V; Manufacturer_Part_Number CL10A475KO8NNNC; JLC 0603
C18: 1000uF; CAPAE830X1050N; Tolerance 20%; Voltage 6.3V; Manufacturer_Part_Number EEE-FK0J102GP
C19: 10nF; C_0603_1608Metric; Tolerance 10%; Voltage 50V; Manufacturer_Part_Number CL10B103KB8NNNC; JLC 0603
C22, C29, C44: 0.1uF; C_0603_1608Metric; Tolerance 10%; Voltage 50V; Manufacturer_Part_Number CL10B104KB8NNNC; JLC 0603
C23: 10uF; C_0603_1608Metric; Voltage 10V; Tolerance 10%; Manufacturer_Part_Number CL10A106KP8NNNC; JLC 0603
C24: 22uF; C_0603_1608Metric; Voltage 6.3V; Tolerance 20%; Manufacturer_Part_Number CL10A226MQ8NRNC; JLC 0603
C26, C28: 1uF; C_0603_1608Metric; Tolerance 10%; Manufacturer_Part_Number CL10B105KO8NNNC; JLC 0603
C27, C45: 1uF; C_0603_1608Metric; Voltage 6.3V; Tolerance 10%; Manufacturer_Part_Number CL10B105KO8NNNC; JLC 0603
D1: RED; LED_0603_1608Metric
D2: GREEN; LED_0603_1608Metric
D3, D4, D5, D6: 1N4148WT; SODFL1608X70N; PARTREV A2; JLC SOD-523
D8: USBLC6-2SC6; SOT95P280X145-6N; PARTREV 5; JLC SOT-23-6
D9: PMEG10010ELRX; SOD123_Generic(W_F_FL); Manufacturer_Part_Number PMEG10010ELRX; Mouser Part Number 771-PMEG10010ELRX
D10: PMEG10020AELPX; SODFL4725X110N; Manufacturer_Part_Number PMEG10020AELPX; Mouser Part Number 771-PMEG10020AELPX
F1, F2: MF-FSMF050X-2; FUSC1608X100N; MPN MF-FSMF050X-2; MOUSER 0.727
FB1, FB2: BLM18PG221SN1D; BEADC1608X95N; Manufacturer_Part_Number BLM18PG221SN1D; Mouser Part Number 81-BLM18PG221SN1D
IC2, IC3: SIP32431DR3-T1GE3; SOT65P210X110-6N; Manufacturer_Part_Number SIP32431DR3-T1GE3; Mouser Part Number 781-SIP32431DR3-GE3
J2: 614105150721; WURTH_614105150721; PARTREV B
J3: B2B-XH-A; SHDR2W64P0X250_1X2_740X575X700P; Manufacturer_Part_Number B2B-XH-A
J4: POWER ON; PinHeader_1x02_P2.54mm_Vertical
L2: 2.2uH; INDC2520X120N; Tolerance 20%; Manufacturer_Part_Number DFE252012P-2R2M=P2; JLC 0603
PS1: NCP161ASN330T1G; SOT95P280X145-5N; Manufacturer_Part_Number NCP161ASN330T1G; Mouser Part Number 863-NCP161ASN330T1G
Q2: FDC638P; SSOT-6; Manufacturer_Part_Number FDC638P; JLC SSOT-6
Q3: IRLML6244TRPBF; SOT95P237X112-3N; PARTREV 10/12/2012; JLC SOT-23-3
Q4, Q5: BSS138; SOT65P210X110-3N; PARTREV 30 Jan 2018; JLC SOT-323-3
Q8: BSS84AK,215; SOT95P230X110-3N; Manufacturer_Part_Number BSS84AK,215; Mouser Part Number 771-BSS84AK215
R10: 0R; R_1206_3216Metric; Tolerance 1%; Power Rating 1/4W; Manufacturer_Part_Number 1206W4F0000T5E; JLC 1206
R11, R12, R13, R49, R54, R55: 0R; R_0603_1608Metric; Tolerance 1%; Power Rating 1/10W; Manufacturer_Part_Number 0603WAF0000T5E; JLC 0603
R34, R47, R48, R51, R53: 1M; R_0603_1608Metric; Tolerance 1%; Power Rating 1/10W; Manufacturer_Part_Number 0603WAF1004T5E; JLC 0603
R35: 0.5R; R_2512_6332Metric; Power Rating 1W; Tolerance 1%; Manufacturer_Part_Number 25121WF500LT4E; JLC 2512
R36, R37: 1K; R_0603_1608Metric; Tolerance 1%; Power Rating 1/10W; Manufacturer_Part_Number 0603WAF1001T5E; JLC 0603
R38, R44, R50: 100K; R_0603_1608Metric; Tolerance 1%; Power Rating 1/10W; Manufacturer_Part_Number 0603WAF1003T5E; JLC 0603
R39: 10K; R_0603_1608Metric; Tolerance 1%; Power Rating 1/10W; Manufacturer_Part_Number 0603WAF1002T5E; JLC 0603
R40, R41: 22R; R_0603_1608Metric; Tolerance 1%; Power Rating 1/10W; Manufacturer_Part_Number 0603WAF220JT5E; JLC 0603
R52: 36.5K; R_0603_1608Metric; Tolerance 0.5%; Power Rating 1/16W; Manufacturer_Part_Number TC0325D3652T5E; JLC 0603
TP20: TestPoint; TestPoint_Pad_D1.0mm
U8: TP4056X; SOP127P600X175-9N; Manufacturer_Part_Number TP4056X-42-ESOP8; JLC SOP-8
U10: TPS63900DSKR; SON50P250X250X80-11N-D; Manufacturer_Part_Number TPS63900DSKR

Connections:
+3V3_EXT: C44.1, IC3.1 (OUT), R13.2; also elsewhere on the board
+3V3_int: C29.1, IC2.1 (OUT), R12.2; also elsewhere on the board
+5V: C20.1, FB2.2, R35.2, TP20.1
BTN_PWR: D3.C; also elsewhere on the board
EN_3V3: PS1.3 (EN), Q2.1, Q2.2, Q2.5, Q2.6, Q8.3, R11.1, R48.1, R53.1, U10.1 (EN)
EN_3V3_EXT: IC3.3 (ON/OFF); also elsewhere on the board
EN_3V3_INT: IC2.3 (ON/OFF); also elsewhere on the board
GND: BT1.-, C16.2, C17.2, C18.2, C19.2, C20.2, C21.2, C22.2, C23.2, C24.2, C26.2, C27.2, C28.2, C29.2, C44.2, C45.2, D8.2, D9.2, D10.2, FB1.2, IC2.2 (GND_1), IC2.5 (GND_2), IC3.2 (GND_1), IC3.5 (GND_2), J3.1, PS1.2 (GND), Q3.2, Q4.2, Q5.2, R34.2, R38.2, R39.1, R50.2, R52.2, R53.2, R54.2, R55.2, U8.1 (TEMP), U8.3 (GND), U8.9 (EP), U10.8 (GND), U10.11 (GND); also elsewhere on the board
MOTION_ALARM: D5.C; also elsewhere on the board
unnamed: BT1.+, J3.2, J4.2
unnamed: C16.1, D1.2 (A), D2.2 (A), R35.1, U8.4 (VCC), U8.8 (CE)
unnamed: C17.1, J2.SH1 (SHIELD), J2.SH2 (SHIELD), R34.1
unnamed: C18.1, F2.1, J4.1
unnamed: D1.1 (K), R36.2
unnamed: D2.1 (K), R37.2
unnamed: D8.1, J2.2
unnamed: D8.3, J2.3
unnamed: D8.4, R41.1
unnamed: D8.6, R40.1
unnamed: F1.1, J2.1
unnamed: FB1.1, J2.5
unnamed: J2.4, R38.1
unnamed: L2.1, U10.7 (LX2)
unnamed: L2.2, U10.9 (LX1)
unnamed: Q3.1, Q4.3, R48.2
unnamed: Q5.1, R49.1
unnamed: R36.1, U8.7 (~CHRG)
unnamed: R37.1, U8.6 (~STDBY)
unnamed: R39.2, U8.2 (PROG)
unnamed: R52.1, U10.3 (CFG1)
unnamed: R54.1, U10.4 (CFG2)
unnamed: R55.1, U10.5 (CFG3)
PWR_OFF: Q4.1, R50.1; also elsewhere on the board
PWR_ON: D3.A, D4.A, D5.A, D6.A, Q2.3, Q3.3, Q8.1, R44.2, R47.2, R49.2
RTC_ALARM: D4.C; also elsewhere on the board
USB_DN: R40.2; also elsewhere on the board
USB_DP: R41.2; also elsewhere on the board
VBATT: C21.1, C23.1, C27.1, D9.1, D10.1, F2.2, PS1.1 (IN), Q2.4, Q8.2, R10.1, R11.2, R44.1, U8.5 (BAT), U10.2 (SEL), U10.10 (VIN); also elsewhere on the board
VBUS: C19.1, C22.1, D8.5, F1.2, FB2.1
V_WKUP: R47.1, R51.1; also elsewhere on the board
WAKEUP: Q5.3, R51.2; also elsewhere on the board
WDG_ALARM: D6.C; also elsewhere on the board

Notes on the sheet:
Battery options (non-rechargeable): Alkaline 2x1.5V or 3x1.5 (AAA, AA, B, C, D) Lithium Thionyl Chloride (Li-SOCL2) 3.6V Lithium Manganese Dioxide (Li-MnO2) 3.0V
Buck-Boost Converter
400mA
RPROG IBAT (Charge Current) 30k 50mA 20k 70mA 10k 130mA 5k 250mA 4k 300mA 3k 400mA 2k 580mA 1.6k 690mA 1.4k 780mA 1.2k 900mA 1.1k 1000mA IBAT = (4.2 / RPROG) 1100 (+-10%) RPROG = 1100 / IBAT (+-10%)
Power dissipation PD = (VCC - (VBAT + VRCC)) IBAT VRCC = V = I * R (0.6 * 0.5 = 0.3V) P = I * V (0.6 * 0.3 = 0.18W) PD = (5 - (3.2 + 0.3)) * 0.6 = 0.9W PD = (5 - (4 + 0.3)) * 0.6 = 0.42W
Charge cuttoff voltage TP4056M 4.2V +-1.5% TP4056X 4.2V +-1% TP4056M Max = 4.2v + 0.063 = 4.263v TP4056X Max = 4.2v + 0.042 = 4.242v
drop between 0.25V and 0.3V reduce power need to be dissipated (TP4056X)
Battery options (rechargeable): Li_Ion or Li-Pol 3xNiMH or 4xNiMH LiFePO4
Sinon la tension remonte quand pulse sur power off
2.2µH 2.3A 0.082R murata
4.7-10u
Invert rising edge wkup
LDO
450mA

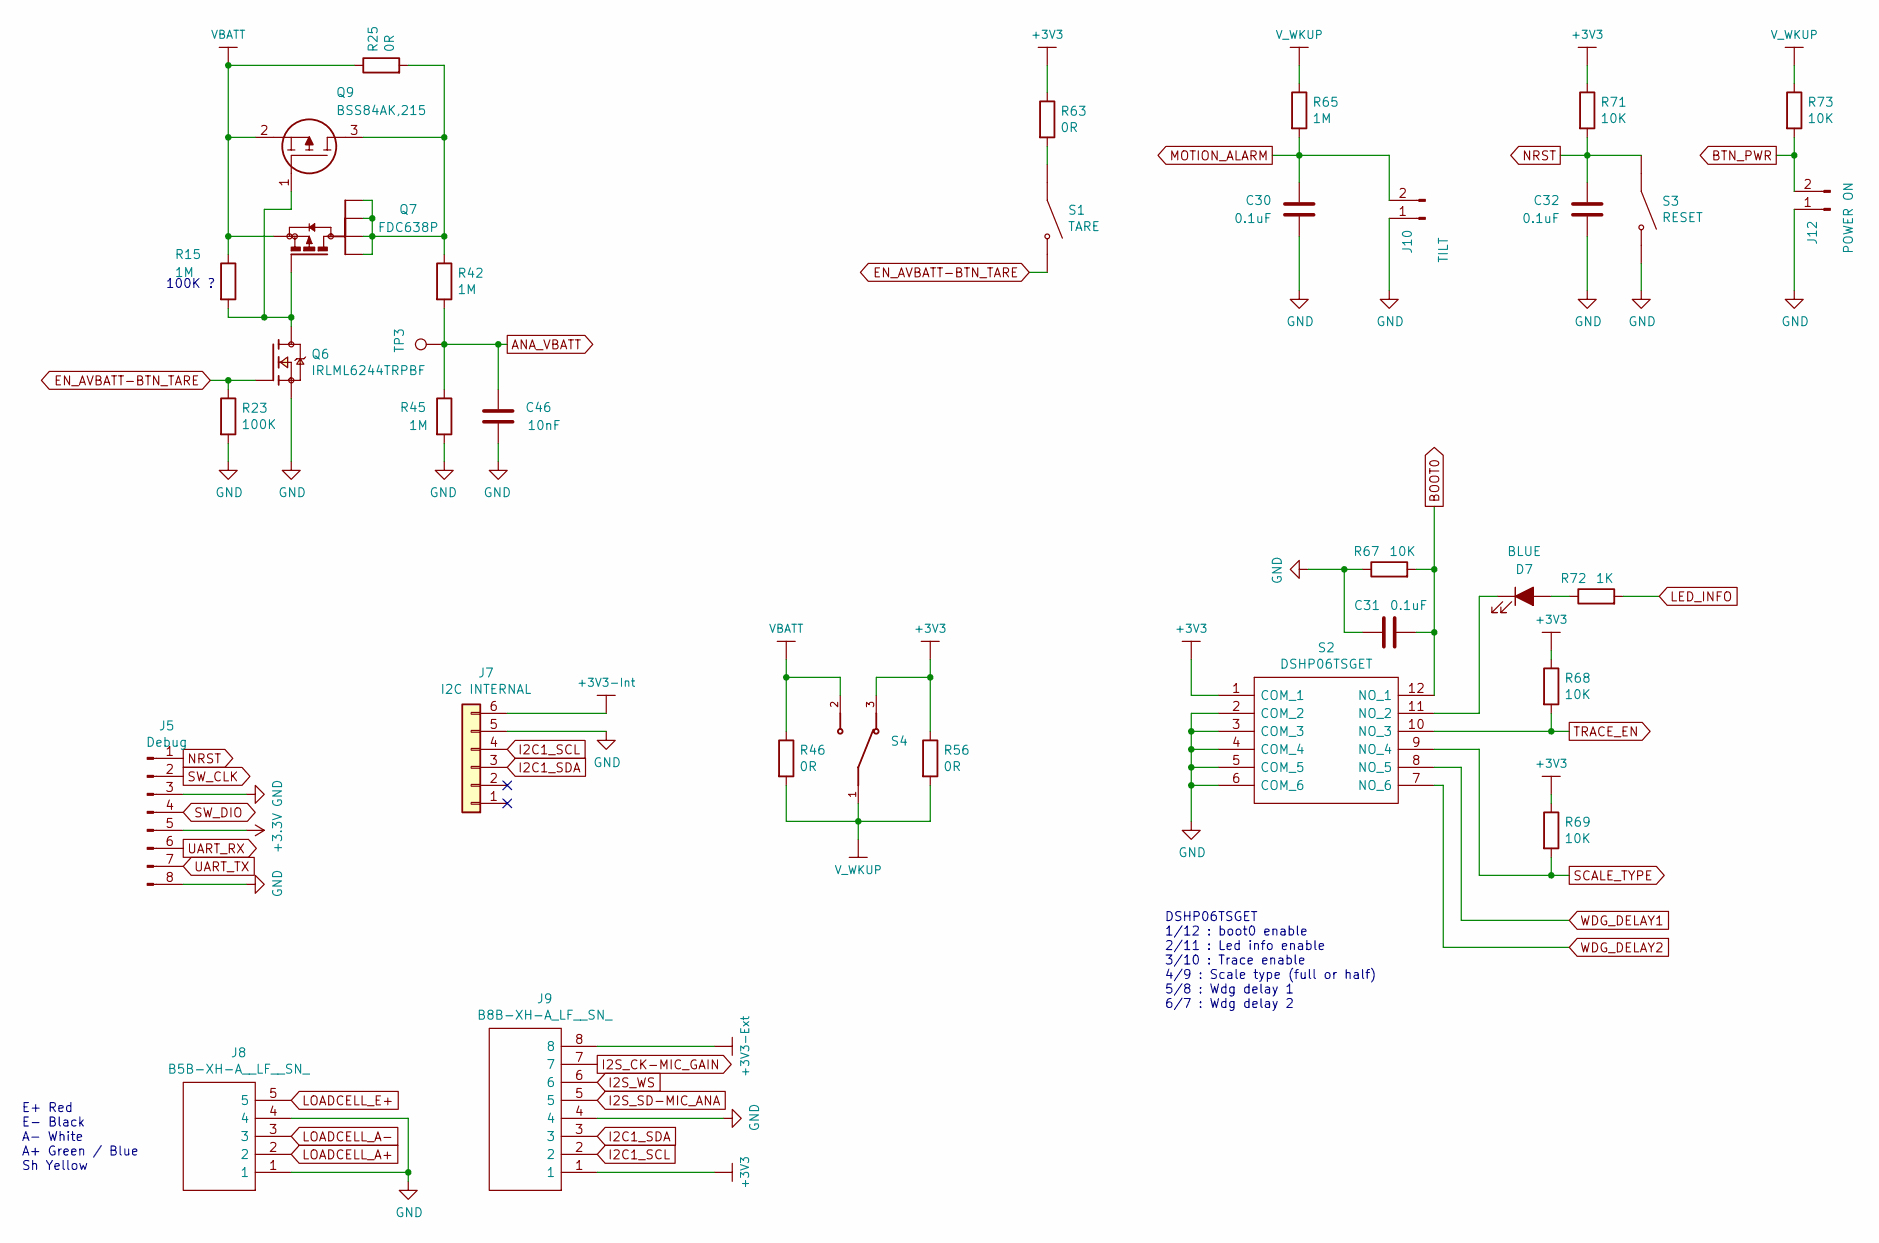
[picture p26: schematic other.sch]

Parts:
C30, C31, C32: 0.1uF; C_0603_1608Metric; Tolerance 10%; Voltage 50V; Manufacturer_Part_Number CL10B104KB8NNNC; JLC 0603
C46: 10nF; C_0603_1608Metric; Tolerance 10%; Voltage 50V; Manufacturer_Part_Number CL10B103KB8NNNC; JLC 0603
D7: BLUE; LED_0603_1608Metric
J5: Debug; PinHeader_1x08_P2.54mm_Vertical
J7: I2C INTERNAL; PinSocket_1x06_P2.54mm_Vertical
J8: B5B-XH-A__LF__SN_; SHDR5W64P0X250_1X5_1490X575X700P; Manufacturer_Part_Number B5B-XH-A (LF)(SN)
J9: B8B-XH-A_LF__SN_; SHDR8W64P0X250_1X8_2240X575X700P; Manufacturer_Part_Number B8B-XH-A(LF)(SN)
J10: TILT; PinHeader_1x02_P2.54mm_Vertical
J12: POWER ON; PinHeader_1x02_P2.54mm_Vertical
Q6: IRLML6244TRPBF; SOT95P237X112-3N; PARTREV 10/12/2012; JLC SOT-23-3
Q7: FDC638P; SSOT-6; Manufacturer_Part_Number FDC638P; JLC SSOT-6
Q9: BSS84AK,215; SOT95P230X110-3N; Manufacturer_Part_Number BSS84AK,215; Mouser Part Number 771-BSS84AK215
R15, R42, R45, R65: 1M; R_0603_1608Metric; Tolerance 1%; Power Rating 1/10W; Manufacturer_Part_Number 0603WAF1004T5E; JLC 0603
R23: 100K; R_0603_1608Metric; Tolerance 1%; Power Rating 1/10W; Manufacturer_Part_Number 0603WAF1003T5E; JLC 0603
R25, R63: 0R; R_0603_1608Metric; Tolerance 1%; Power Rating 1/10W; Manufacturer_Part_Number 0603WAF0000T5E; JLC 0603
R46, R56: 0R; R_1206_3216Metric; Tolerance 1%; Power Rating 1/4W; Manufacturer_Part_Number 1206W4F0000T5E; JLC 1206
R67, R68, R69, R71, R73: 10K; R_0603_1608Metric; Tolerance 1%; Power Rating 1/10W; Manufacturer_Part_Number 0603WAF1002T5E; JLC 0603
R72: 1K; R_0603_1608Metric; Tolerance 1%; Power Rating 1/10W; Manufacturer_Part_Number 0603WAF1001T5E; JLC 0603
S1: TARE; SW_PUSH
S2: DSHP06TSGET; Manufacturer_Part_Number DSHP06TSGET
S3: RESET; SW_PUSH
S4: MSS-102559-14A-D; SW_MSS-102559-14A-D; PARTREV 1.0
TP3: TestPoint; TestPoint_Pad_D1.0mm

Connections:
+3V3_EXT: J9.8; also elsewhere on the board
+3V3_int: J7.6; also elsewhere on the board
ANA_VBATT: C46.1, R42.2, R45.1, TP3.1; also elsewhere on the board
BOOT0: C31.1, R67.2, S2.12 (NO_1); also elsewhere on the board
BTN_PWR: J12.2, R73.2; also elsewhere on the board
EN_AVBATT-BTN_TARE: Q6.1, R23.1, S1.3, S1.4; also elsewhere on the board
GND: C30.2, C31.2, C32.2, C46.2, J5.3, J5.8, J7.5, J8.1, J8.4, J9.4, J10.1, J12.1, Q6.2, R23.2, R45.2, R67.1, S2.2 (COM_2), S2.3 (COM_3), S2.4 (COM_4), S2.5 (COM_5), S2.6 (COM_6), S3.3, S3.4; also elsewhere on the board
I2C1_SCL: J7.4, J9.2; also elsewhere on the board
I2C1_SDA: J7.3, J9.3; also elsewhere on the board
I2S_CK-MIC_GAIN: J9.7; also elsewhere on the board
I2S_SD-MIC_ANA: J9.5; also elsewhere on the board
I2S_WS: J9.6; also elsewhere on the board
LED_INFO: R72.2; also elsewhere on the board
LOADCELL_A+: J8.2; also elsewhere on the board
LOADCELL_A-: J8.3; also elsewhere on the board
LOADCELL_E+: J8.5; also elsewhere on the board
MOTION_ALARM: C30.1, J10.2, R65.2; also elsewhere on the board
NRST: C32.1, J5.1, R71.2, S3.1, S3.2; also elsewhere on the board
unnamed: D7.1 (K), S2.11 (NO_2)
unnamed: D7.2 (A), R72.1
unnamed: Q6.3, Q7.3, Q9.1, R15.2
unnamed: Q7.1, Q7.2, Q7.5, Q7.6, Q9.3, R25.2, R42.1
unnamed: R63.2, S1.1, S1.2
SCALE_TYPE: R69.2, S2.9 (NO_4); also elsewhere on the board
SW_CLK: J5.2; also elsewhere on the board
SW_DIO: J5.4; also elsewhere on the board
TRACE_EN: R68.2, S2.10 (NO_3); also elsewhere on the board
UART_RX: J5.6; also elsewhere on the board
UART_TX: J5.7; also elsewhere on the board
VBATT: Q7.4, Q9.2, R15.1, R25.1, R46.1, S4.2; also elsewhere on the board
V_WKUP: R46.2, R56.2, R65.1, R73.1, S4.1; also elsewhere on the board
WDG_DELAY1: S2.8 (NO_5); also elsewhere on the board
WDG_DELAY2: S2.7 (NO_6); also elsewhere on the board

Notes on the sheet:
E+ Red E- Black A- White A+ Green / Blue Sh Yellow
DSHP06TSGET 1/12 : boot0 enable 2/11 : Led info enable 3/10 : Trace enable 4/9 : Scale type (full or half) 5/8 : Wdg delay 1 6/7 : Wdg delay 2
100K ?

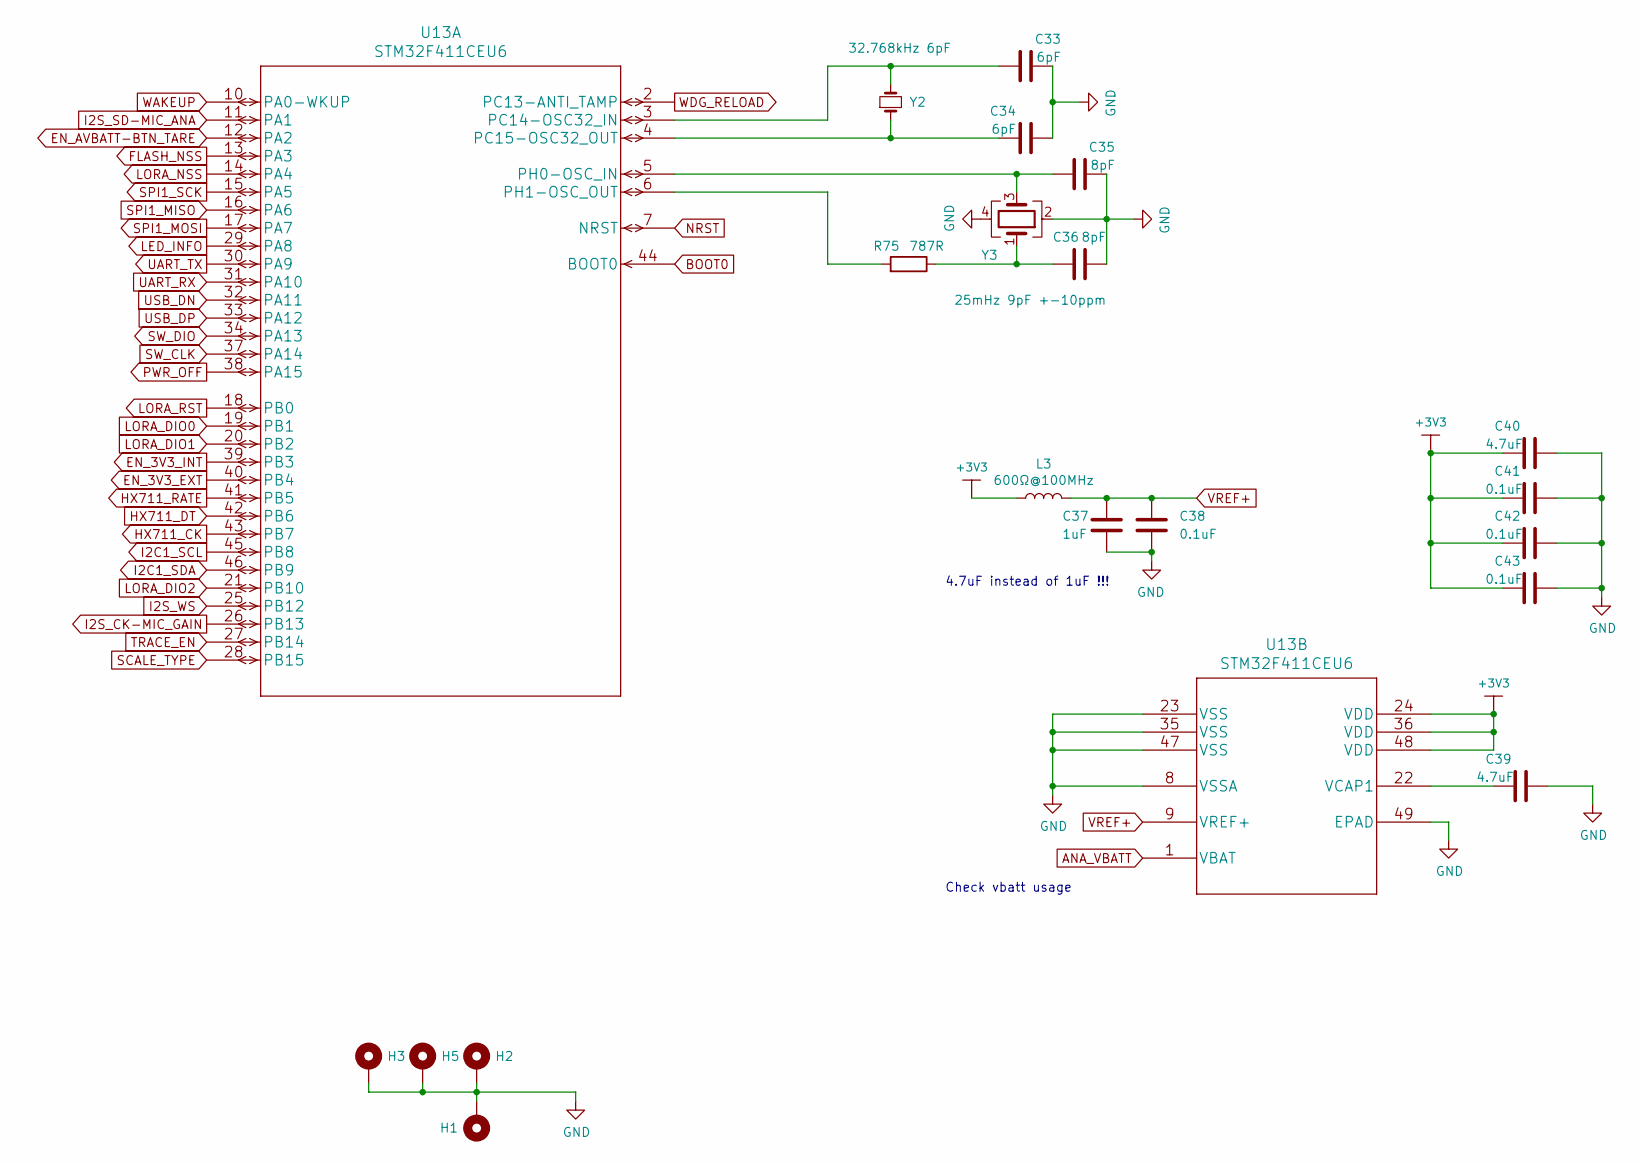
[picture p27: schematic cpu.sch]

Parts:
C33, C34: 6pF; C_0402_1005Metric; Voltage 25V; Manufacturer_Part_Number GCM1555C1H6R0BA16D; JLC 0402
C35, C36: 8pF; C_0402_1005Metric; Voltage 50V; Manufacturer_Part_Number GJM1555C1H8R0BB01D; JLC 0402
C37: 1uF; C_0402_1005Metric; Tolerance 10%; Voltage 6.3V; Manufacturer_Part_Number CL05B105KQ5NQNC; JLC 0402
C38, C41, C42, C43: 0.1uF; C_0402_1005Metric; Tolerance 10%; Voltage 16V; Manufacturer_Part_Number CL05B104KO5NNNC; JLC 0402
C39, C40: 4.7uF; C_0402_1005Metric; Tolerance 10%; Voltage 10V; Manufacturer_Part_Number GRM155R61A475KEAAD; JLC 0402
H1, H2, H3, H5: MountingHole_Pad; MountingHole_2.7mm_M2.5_Pad_Via
L3: 600Ω@100MHz; L_0603_1608Metric; Tolerance 25%; Manufacturer_Part_Number FCM1608KF-601T05; JLC 0603
R75: 787R; R_0402_1005Metric; Tolerance 1%; Power Rating 1/16W; Manufacturer_Part_Number 0402WGF7870TCE; JLC 0402
U13: STM32F411CEU6; Manufacturer_Part_Number STM32F411CEU6; JLC UFQFPN-48
Y2: 32.768kHz 6pF; XTAL_ABS07-120-32.768KHZ-T; Manufacturer_Part_Number SC-32S32.768kHz20PPM6pF; JLC 3215
Y3: 25mHz 9pF +-10ppm; X322525MMB4SI; Manufacturer_Part_Number X1E0000210621; JLC 3225

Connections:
ANA_VBATT: U13.1 (VBAT); also elsewhere on the board
BOOT0: U13.44 (BOOT0); also elsewhere on the board
EN_3V3_EXT: U13.40 (PB4); also elsewhere on the board
EN_3V3_INT: U13.39 (PB3); also elsewhere on the board
EN_AVBATT-BTN_TARE: U13.12 (PA2); also elsewhere on the board
FLASH_NSS: U13.13 (PA3); also elsewhere on the board
GND: C33.2, C34.2, C35.2, C36.2, C37.1, C38.1, C39.1, C40.1, C41.1, C42.1, C43.1, H1.1, H2.1, H3.1, H5.1, U13.8 (VSSA), U13.23 (VSS), U13.35 (VSS), U13.47 (VSS), U13.49 (EPAD), Y3.2, Y3.4; also elsewhere on the board
HX711_CK: U13.43 (PB7); also elsewhere on the board
HX711_DT: U13.42 (PB6); also elsewhere on the board
HX711_RATE: U13.41 (PB5); also elsewhere on the board
I2C1_SCL: U13.45 (PB8); also elsewhere on the board
I2C1_SDA: U13.46 (PB9); also elsewhere on the board
I2S_CK-MIC_GAIN: U13.26 (PB13); also elsewhere on the board
I2S_SD-MIC_ANA: U13.11 (PA1); also elsewhere on the board
I2S_WS: U13.25 (PB12); also elsewhere on the board
LED_INFO: U13.29 (PA8); also elsewhere on the board
LORA_DIO0: U13.19 (PB1); also elsewhere on the board
LORA_DIO1: U13.20 (PB2); also elsewhere on the board
LORA_DIO2: U13.21 (PB10); also elsewhere on the board
LORA_NSS: U13.14 (PA4); also elsewhere on the board
LORA_RST: U13.18 (PB0); also elsewhere on the board
NRST: U13.7 (NRST); also elsewhere on the board
unnamed: C33.1, U13.3 (PC14-OSC32_IN), Y2.2
unnamed: C34.1, U13.4 (PC15-OSC32_OUT), Y2.1
unnamed: C35.1, U13.5 (PH0-OSC_IN), Y3.3
unnamed: C36.1, R75.1, Y3.1
unnamed: C39.2, U13.22 (VCAP1)
unnamed: R75.2, U13.6 (PH1-OSC_OUT)
PWR_OFF: U13.38 (PA15); also elsewhere on the board
SCALE_TYPE: U13.28 (PB15); also elsewhere on the board
SPI1_MISO: U13.16 (PA6); also elsewhere on the board
SPI1_MOSI: U13.17 (PA7); also elsewhere on the board
SPI1_SCK: U13.15 (PA5); also elsewhere on the board
SW_CLK: U13.37 (PA14); also elsewhere on the board
SW_DIO: U13.34 (PA13); also elsewhere on the board
TRACE_EN: U13.27 (PB14); also elsewhere on the board
UART_RX: U13.31 (PA10); also elsewhere on the board
UART_TX: U13.30 (PA9); also elsewhere on the board
USB_DN: U13.32 (PA11); also elsewhere on the board
USB_DP: U13.33 (PA12); also elsewhere on the board
VREF+: C37.2, C38.2, L3.2, U13.9 (VREF+)
WAKEUP: U13.10 (PA0-WKUP); also elsewhere on the board
WDG_RELOAD: U13.2 (PC13-ANTI_TAMP); also elsewhere on the board

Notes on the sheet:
Check vbatt usage
4.7uF instead of 1uF !!!

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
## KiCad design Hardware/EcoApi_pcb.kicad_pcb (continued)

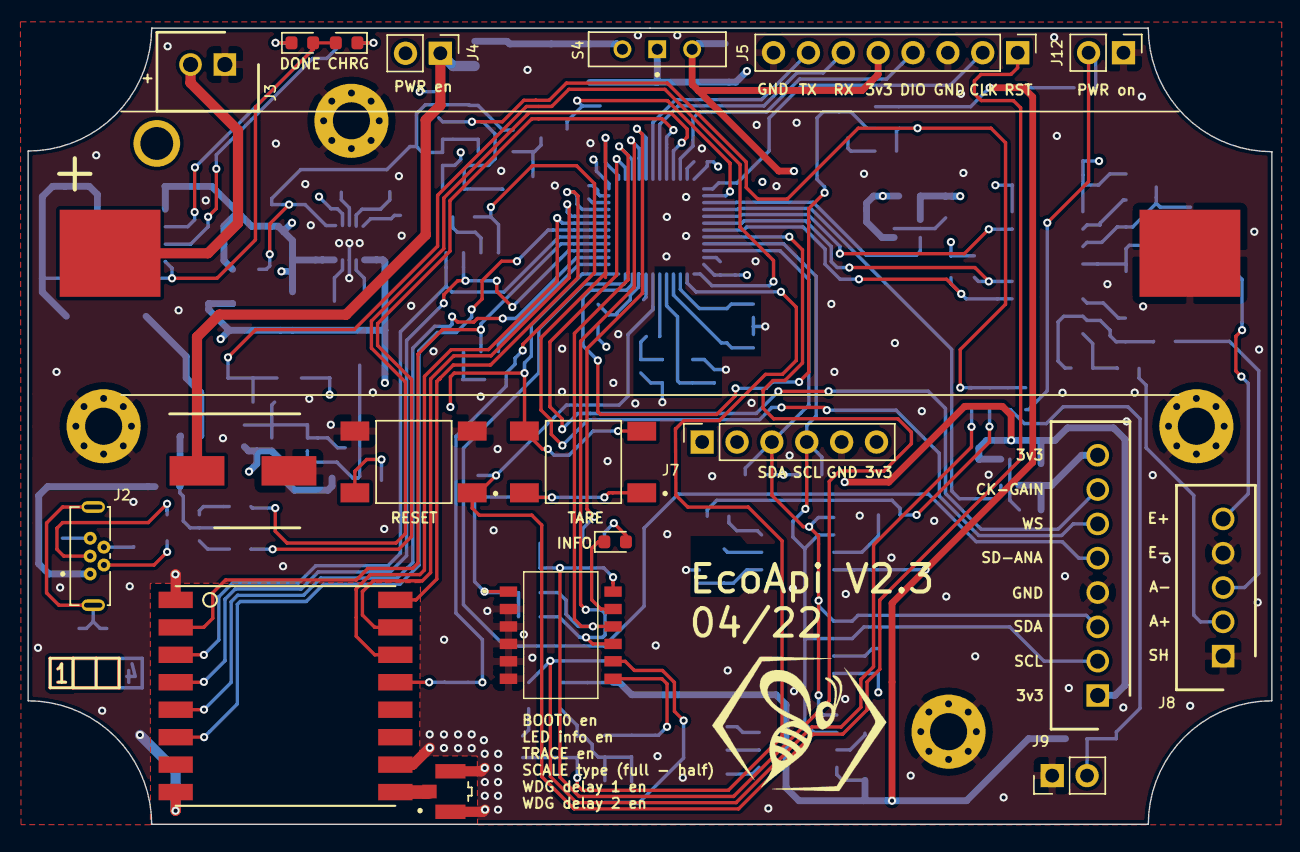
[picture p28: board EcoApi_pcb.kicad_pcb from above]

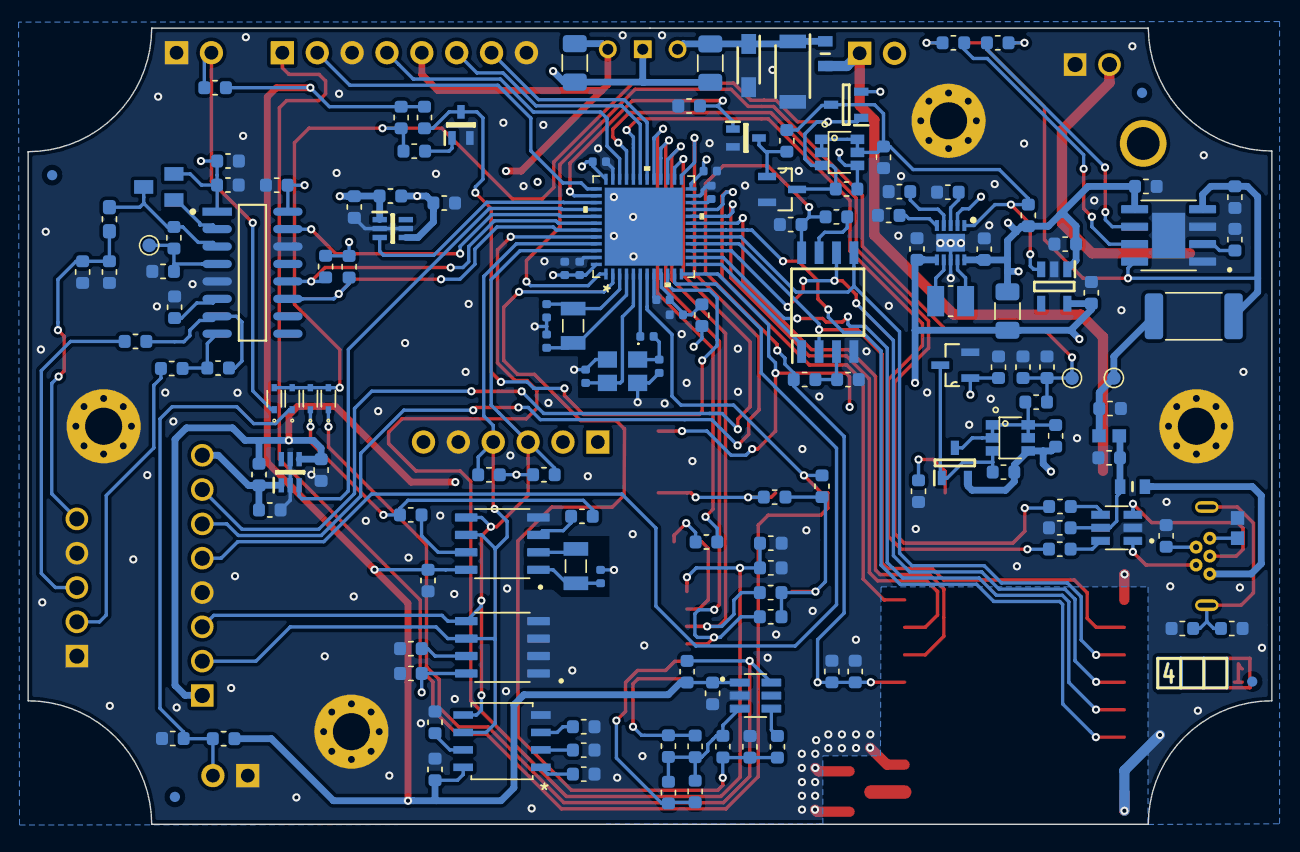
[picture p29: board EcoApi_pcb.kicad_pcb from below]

Board: 4 copper layers, 90.6 x 58.0 mm, 174 parts (149 on the bottom side), 109 nets.

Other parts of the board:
LayerIcon04: VAL**; LayerNumber_4

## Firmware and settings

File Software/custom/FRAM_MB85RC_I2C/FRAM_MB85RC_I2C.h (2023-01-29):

/**************************************************************************/
/*! 
    @file     FRAM_MB85RC_I2C.h
    @author   SOSAndroid.fr (E. Ha.)
	
    @section  HISTORY

    v1.0 - First release
	v1.0.1 - Robustness enhancement
	v1.0.2 - fix constructor, introducing byte move in memory
	v1.0.3 - fix writeLong() function
	v1.0.4 - fix constructor call error
	v1.0.5 - Enlarge density chip support by making check more flexible, Error codes not anymore hardcoded, add connect example, add Cypress FM24 & CY15B series comment.
	v1.1.0b - adding support for devices without device IDs + 4K & 16 K devices support
	v1.2.0 - Uses reinterpret_cast instead of bit shift / masking for performance. Breaks backward compatibility with previous code - See PR#6
	v1.2.1 - Fix comment line #76 (issue #11), max address define statement for 512K & 1M chips (issue 13)
	v1.2.2 - Fix issue #16

    Driver for the MB85RC I2C FRAM from Fujitsu.
	
    @section LICENSE

    Software License Agreement (BSD License)

    Copyright (c) 2013, SOSAndroid.fr (E. Ha.)
    All rights reserved.

    Redistribution and use in source and binary forms, with or without
    modification, are permitted provided that the following conditions are met:
    1. Redistributions of source code must retain the above copyright
    notice, this list of conditions and the following disclaimer.
    2. Redistributions in binary form must reproduce the above copyright
    notice, this list of conditions and the following disclaimer in the
    documentation and/or other materials provided with the distribution.
    3. Neither the name of the copyright holders nor the
    names of its contributors may be used to endorse or promote products
    derived from this software without specific prior written permission.

    THIS SOFTWARE IS PROVIDED BY THE COPYRIGHT HOLDERS ''AS IS'' AND ANY
    EXPRESS OR IMPLIED WARRANTIES, INCLUDING, BUT NOT LIMITED TO, THE IMPLIED
    WARRANTIES OF MERCHANTABILITY AND FITNESS FOR A PARTICULAR PURPOSE ARE
    DISCLAIMED. IN NO EVENT SHALL THE COPYRIGHT HOLDER BE LIABLE FOR ANY
    DIRECT, INDIRECT, INCIDENTAL, SPECIAL, EXEMPLARY, OR CONSEQUENTIAL DAMAGES
    (INCLUDING, BUT NOT LIMITED TO, PROCUREMENT OF SUBSTITUTE GOODS OR SERVICES;
    LOSS OF USE, DATA, OR PROFITS; OR BUSINESS INTERRUPTION) HOWEVER CAUSED AND
    ON ANY THEORY OF LIABILITY, WHETHER IN CONTRACT, STRICT LIABILITY, OR TORT
    (INCLUDING NEGLIGENCE OR OTHERWISE) ARISING IN ANY WAY OUT OF THE USE OF THIS
    SOFTWARE, EVEN IF ADVISED OF THE POSSIBILITY OF SUCH DAMAGE.
*/
/**************************************************************************/
#ifndef _FRAM_MB85RC_I2C_H_
#define _FRAM_MB85RC_I2C_H_

#if ARDUINO >= 100
 #include <Arduino.h>
#else
 #include <WProgram.h>
#endif

#include <Wire.h>

// Enabling debug I2C - comment to disable / normal operations
#ifndef SERIAL_DEBUG
#define SERIAL_DEBUG 0
#endif

// IDs
//Manufacturers codes
#define FUJITSU_MANUFACT_ID 0x00A
#define CYPRESS_MANUFACT_ID 0x004
#define MANUALMODE_MANUFACT_ID 0xF00
#define MANUALMODE_PRODUCT_ID 0xF00
#define MANUALMODE_DENSITY_ID 0xF00

// The density codes gives the memory's adressing scheme
#define DENSITY_MB85RC04V 0x00		// 4K
#define DENSITY_MB85RC64TA 0x03		// 64K
#define DENSITY_MB85RC256V 0x05		// 256K
#define DENSITY_MB85RC512T 0x06		// 512K
#define DENSITY_MB85RC1MT 0x07		// 1M

#define DENSITY_CY15B128J 0x01		// 128K - FM24V01A also
#define DENSITY_CY15B256J 0x02		// 256K - FM24V02A also
#define DENSITY_FM24V05 0x03		// 512K
#define DENSITY_FM24V10 0x04		// 1024K

// Devices MB85RC16, MB85RC16V, MB85RC64A, MB85RC64V and MB85RC128A do not support Device ID reading
// 			FM24W256,FM24CL64B, FM24C64B, FM24C16B, FM24C04B, FM24CL04B

#define MAXADDRESS_04 512
#define MAXADDRESS_16 2048
#define MAXADDRESS_64 8192
#define MAXADDRESS_128 16384
#define MAXADDRESS_256 32768
#define MAXADDRESS_512 65535
#define MAXADDRESS_1024 65535 // 1M devices are in fact managed as 2 512 devices from lib point of view > create 2 instances of the object with each a differnt address

// Adresses
#define MB85RC_ADDRESS_A000   0x50
#define MB85RC_ADDRESS_A001   0x51
#define MB85RC_ADDRESS_A010   0x52
#define MB85RC_ADDRESS_A011   0x53
#define MB85RC_ADDRESS_A100   0x54
#define MB85RC_ADDRESS_A101   0x55
#define MB85RC_ADDRESS_A110   0x56
#define MB85RC_ADDRESS_A111   0x57
#define MB85RC_DEFAULT_ADDRESS   MB85RC_ADDRESS_A000

//Special commands
#define MASTER_CODE	0xF8
#define SLEEP_MODE	0x86 //Cypress codes, not used here	
#define HIGH_SPEED	0x08 //Cypress codes, not used here

// Managing Write protect pin
#define MANAGE_WP false //false if WP pin remains not connected
#define DEFAULT_WP_PIN	13 //write protection pin - active high, write enabled when low
#define DEFAULT_WP_STATUS  false //false means protection is off - write is enabled

// Error management
#define ERROR_0 0 // Success    
#define ERROR_1 1 // Data too long to fit the transmission buffer on Arduino
#define ERROR_2 2 // received NACK on transmit of address
#define ERROR_3 3 // received NACK on transmit of data
#define ERROR_4 4 // Serial seems not available
#define ERROR_5 5 // Not referenced device ID
#define ERROR_6 6 // Unused
#define ERROR_7 7 // Fram chip unidentified
#define ERROR_8 8 // Number of bytes asked to read null
#define ERROR_9 9 // Bit position out of range
#define ERROR_10 10 // Not permitted opération
#define ERROR_11 11 // Memory address out of range


class FRAM_MB85RC_I2C {
 public:
	FRAM_MB85RC_I2C(void);
	FRAM_MB85RC_I2C(uint8_t address, boolean wp);
	FRAM_MB85RC_I2C(uint8_t address, boolean wp, int pin);
	FRAM_MB85RC_I2C(uint8_t address, boolean wp, int pin, uint16_t chipDensity);
	
	boolean	begin(void);
	byte	checkDevice(void);
	byte	readBit(uint16_t framAddr, uint8_t bitNb, byte *bit);
	byte	setOneBit(uint16_t framAddr, uint8_t bitNb);
	byte	clearOneBit(uint16_t framAddr, uint8_t bitNb);
	byte	toggleBit(uint16_t framAddr, uint8_t bitNb);
	byte	readArray (uint16_t framAddr, uint16_t items, uint8_t value[]);
	byte	writeArray (uint16_t framAddr, uint16_t items, uint8_t value[]);
	byte	readByte (uint16_t framAddr, uint8_t *value);
	byte	writeByte (uint16_t framAddr, uint8_t value);
	byte	copyByte (uint16_t origAddr, uint16_t destAddr);
	byte	readWord(uint16_t framAddr, uint16_t *value);
	byte	writeWord(uint16_t framAddr, uint16_t value);
	byte	readLong(uint16_t framAddr, uint32_t *value);
	byte	writeLong(uint16_t framAddr, uint32_t value);
	byte	getOneDeviceID(uint8_t idType, uint16_t *id);
	boolean	isReady(void);
	boolean	getWPStatus(void);
	byte	enableWP(void);
	byte	disableWP(void);
	byte	eraseDevice(void);
  
 private:
	uint8_t	i2c_addr;
	boolean	_framInitialised;
	boolean	_manualMode;
	uint16_t	manufacturer;
	uint16_t	productid; 
	uint16_t	densitycode;
	uint16_t	density;
	uint16_t	maxaddress;

	int	wpPin;
	boolean	wpStatus;

	byte	getDeviceIDs(void);	
	byte	setDeviceIDs(void);
	byte	initWP(boolean wp);
	byte	deviceIDs2Serial(void);
	void	I2CAddressAdapt(uint16_t framAddr);
};

#endif

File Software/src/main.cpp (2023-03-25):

/************************************************************************************/ /**
                                                                                        *
                                                                                        *	\file		main.cpp
                                                                                        *
                                                                                        *	\brief
                                                                                        *
                                                                                        *	\date		2 nov. 2021
                                                                                        *
                                                                                        *	\author		ecoapi
                                                                                        *
                                                                                        ***************************************************************************************/

/***************************************************************************************/
/*	Includes
/***************************************************************************************/
#include "board.h"
#include <Wire.h>
#include "trace.h"
#include "power.h"
#include "system.h"
#include "rtc.h"
#if (USE_EEPROM == 1)
#include "eeprom.h"
#endif
#include "ramret.h"
#include "sensor.h"
#include "lora.h"
#include "wdg.h"
#include "utils.h"

/***************************************************************************************/
/*	Defines
/***************************************************************************************/
#define HW_VERSION 2

#define TEST_USB_CDC (0)
#define TEST_AUDIO (0) 
#define TEST_HARDWARE (0) 
#if (TEST_HARDWARE == 1) || (TEST_AUDIO == 1) || (TEST_USB_CDC == 1)
#define LORA_ENABLE (0)
#else
#define LORA_ENABLE (1)
#endif
#define WDG_ENABLE (0)

#define STM32_UUID ((uint32_t *)0x1FFF7A10) // F4

#define MIN_TO_SEC(min) (min * 60)

/***************************************************************************************/
/*	Local variables
/***************************************************************************************/
typedef enum e_DATA_STATE {
  e_dataStateDefault = 0,
  e_dataStateNotChange,
  e_dataStateQueued,
  e_dataStateSended,
  e_dataStateSendFailed,
  e_dataStateStandby,
} e_DATA_STATE;

static e_DATA_STATE e_dataState = e_dataStateDefault;

#if (USE_EEPROM == 1)
static t_Eeprom t_eeprom;
#endif

static t_RamRet t_ramRet;
static time_t startTime = 0;
static uint32_t startDataQueuedTime = 0;

// IWatchdogClass watchdog = IWatchdogClass();

/***************************************************************************************/
/*	Local Functions prototypes
/***************************************************************************************/
static int32_t lora_sendDataCallback(uint8_t *payload, uint8_t payloadSize, uint8_t *p_sendSize);
static void lora_eventCallback(e_LORA_EVENT e_event, void *pv_data, uint32_t size);
#if (STANDBY_ENABLE == 0)
static void lora_wakeupCallback(void);
#endif
static void gotoSleep(void);
static void setLowConsumption(void);
#if (TEST_HARDWARE == 1)
static void test_hardware(void);
#endif

/***************************************************************************************
 *
 *	\fn		void setup(void)
 *	\brief
 *
 ***************************************************************************************/
void setup(void) {
  // system_setBorLevel(OB_BOR_LEVEL1);

  digitalWrite(LED_INFO, LOW);
  pinMode(LED_INFO, OUTPUT);

  //pinMode(MIC_ANA, INPUT_ANALOG);

  // clock debug with mco pin
  // HAL_RCC_MCOConfig(RCC_MCO1, RCC_MCO1SOURCE_HSI, RCC_MCODIV_1);

  SET_3V3_EXTERNAL(true);

  int32_t powerInit = power_init();

  trace_init(&Serial1);

  if(power_isPoweredOn())
    delay(1000);

  Wire.setSCL(I2C1_SCL);
  Wire.setSDA(I2C1_SDA);

  Wire.setClock(400000);
  Wire.begin();

#if (USE_EEPROM == 1)
  int32_t eepromInit = eeprom_init(&t_eeprom);
#endif

  int32_t rtcInit = rtc_init(&startTime);

  int32_t ramRetInit = ramret_init(&t_ramRet, rtc_isLostPower());

  TRACE_CrLf("[BOOT] EcoApi BeeHive Monitor [hw %d, sw %d]", HW_VERSION, SW_REVISION);
#if (USE_EEPROM == 1)
  TRACE_CrLf("[BOOT] tx freq %d, cpu uuid %08X%08X%08X", t_eeprom.sendFrequency, STM32_UUID[0], STM32_UUID[1], STM32_UUID[2]);
#else
  TRACE_CrLf("[BOOT] tx freq %d, cpu uuid %08X%08X%08X", t_ramRet.sendFrequency, STM32_UUID[0], STM32_UUID[1], STM32_UUID[2]);
#endif

  /*if(!watchdog.isEnabled()) {
    TRACE_CrLf("[WDG] init ko");
  } else {
    TRACE_CrLf("[WDG] init ok");
  } */

  if (powerInit == STANDBY_RESUMED) {
    TRACE_CrLf("[POWER] resume standby");
  } else if (powerInit != OK) {
    TRACE_CrLf("[POWER] init ko");
  }

  // if(power_isWatchdogReset())
  //   t_ramRet.boot++;

  power_traceState();

#if (USE_EEPROM == 1)
  if (OK != eepromInit) {
    TRACE_CrLf("[EEPROM] error");
    delay(1000);
    system_reset();
  } else {
    if (eeprom_isNew())
      TRACE_CrLf("[EEPROM] initialized to default");
    else
      TRACE_CrLf("[EEPROM] restored");
  }
#endif

  if (OK != rtcInit) {
    TRACE_CrLf("[RTC] error %d", rtcInit);
    delay(1000);
    system_reset();
  } else {
    if (rtc_isLostPower())
      TRACE_CrLf("[RTC] init");
    else {
      TRACE_CrLf("[RTC] ok, timestamp: %d, sleep time %d, last send time %d, last update time %d", (uint32_t) startTime,
                                                                                                   (uint32_t) startTime - t_ramRet.dataCommon.lastSendTime,
                                                                                                   t_ramRet.dataCommon.lastSendTime,
                                                                                                   t_ramRet.dataCommon.lastUpdateTime);

      /*TRACE_CrLf("rtc is wkup %d, rtc is en %d, is p rst %d, is sw rst %d, is pwr on %d, pwr sb %d", rtc_isWakeUpRtc(),
                                                                                       rtc_isEnabledWakeUpRtc(),
                                                                                       power_isPinReset(),
                                                                                       power_isSoftwareReset(),
                                                                                       power_isPoweredOn(),
                                                                                       powerInit == STANDBY_RESUMED);*/

      if((FALSE == rtc_isWakeUpRtc()) &&
         (TRUE == rtc_isEnabledWakeUpRtc()) &&
         (TRUE == power_isPoweredOn()) || (TRUE == power_isSoftwareReset()) || (powerInit == STANDBY_RESUMED))
        t_ramRet.telemetryData.contentInfo.details.motionDetectionOrPowerOn = TRUE;
      else
        t_ramRet.telemetryData.contentInfo.details.motionDetectionOrPowerOn = FALSE;

      if(t_ramRet.telemetryData.contentInfo.details.motionDetectionOrPowerOn) {
        TRACE_CrLf("[POWER] motion or power on detected, last time %d", t_ramRet.dataCommon.lastSendMotionOrPowerTime);

        if((t_ramRet.dataCommon.lastSendMotionOrPowerTime + DEFAULT_MOTION_DETECT_PERIOD) > startTime) {
#if (TEST_HARDWARE == 0) && (TEST_AUDIO == 0) && (TEST_USB_CDC == 0)
          TRACE_CrLf("[POWER] go standby");
         
          //lora_suspend();

          pinMode(LED_INFO, INPUT_ANALOG);

          pinMode(MIC_ANA, INPUT_ANALOG);

          SET_3V3_EXTERNAL(false);

          trace_setState(false);  

          Wire.end();

          power_sleep(e_SLEEP_MODE_STANDBY, e_WAKEUP_TYPE_RTC, DEFAULT_STANDBY_MOTION_DETECT_TIMEOUT, WAKEUP_PIN);
#endif          
        }  
      } 
    }    
  }

  if (OK != ramRetInit) {
    TRACE_CrLf("[RRAM] error");
    delay(1000);
    system_reset();
  } else {
    if (ramret_isNew())
      TRACE_CrLf("[RRAM] initialized to default");
    else {
      if((t_ramRet.dataCommon.lastUpdateTime + DEFAULT_UPDATE_TIME_PERIOD) < startTime) {
        t_ramRet.dataCommon.lastUpdateTime = startTime;
        t_ramRet.dataCommon.timeUpdated = FALSE;

        TRACE_CrLf("[RRAM] restored, ask update time");
      } else
        TRACE_CrLf("[RRAM] restored");
    }  
  }

#if (TEST_USB_CDC == 1)
  SerialUSB.begin(115200);
#elif (TEST_AUDIO == 1)
  uint32_t vRef = analog_getInternalVref();

#if (USE_EEPROM == 1)
  audio_setup(&t_eeprom, vRef, audio_detectType());
#else
  audio_setup(&t_ramRet, vRef, audio_detectType());
#endif
#elif (TEST_HARDWARE == 1)
  test_hardware();
#else
#if (LORA_ENABLE == 1)
  if (t_ramRet.dataCommon.sendAudioData == FALSE) {
#if (USE_EEPROM == 1)
    if (sensor_setup(&t_eeprom, &t_ramRet, FLAG_ALL_WITHOUT_AUDIO) != OK) {
#else
    if (sensor_setup(&t_ramRet, &t_ramRet, FLAG_ALL_WITHOUT_AUDIO) != OK) {
#endif
      // todo qos
    }
  } else {
#if (USE_EEPROM == 1)    
    if (sensor_setup(&t_eeprom, &t_ramRet, FLAG_AUDIO_INFO) != OK) {
#else
    if (sensor_setup(&t_ramRet, &t_ramRet, FLAG_ALL_WITHOUT_AUDIO) != OK) {
#endif      
      // todo qos
    }
  }

#if (STANDBY_ENABLE == 1)
  lora_setup(&t_ramRet, &lora_sendDataCallback, &lora_eventCallback);
#else
  lora_setup(&t_ramRet, &lora_sendDataCallback, &lora_eventCallback, &lora_wakeupCallback);

  t_ramRet.lastSendTime = 0;
#endif
#else
  // if(t_ramRet.audioSettings.sendData == FALSE) {
#if (USE_EEPROM == 1)
  if (sensor_setup(&t_eeprom, &t_ramRet, FLAG_ALL_WITHOUT_AUDIO /*| FLAG_AUDIO_INFO*/) != OK) {
#else
  if (sensor_setup(&t_ramRet, &t_ramRet, FLAG_ALL_WITHOUT_AUDIO /*| FLAG_AUDIO_INFO*/) != OK) {
#endif

    // todo qos
  }
  //}
#endif

  if (OK != ramret_save(&t_ramRet)) {
    delay(1000);
    system_reset();
  }
#endif

  //display_mallinfo();
}

/***************************************************************************************
 *
 *	\fn		void loop(void)
 *	\brief
 *
 ***************************************************************************************/
void loop(void) {
#if (TEST_USB_CDC == 1)
  static bool serialUSB_Enable = false;

  bool dtrState = SerialUSB.dtr();

  if(!serialUSB_Enable && dtrState) {
    SerialUSB.println("USB serial enable");
    
    TRACE_CrLf("USB serial enable");
    
    serialUSB_Enable = true;
  } else if(serialUSB_Enable && !dtrState) {
    SerialUSB.println("USB serial disable");

    TRACE_CrLf("USB serial disable");

    serialUSB_Enable = false;
  }

  if(serialUSB_Enable) {
    while(SerialUSB.available()) {
      char rc = SerialUSB.read();// read a character
      TRACE("%c", rc);
     }
  }
#elif (TEST_AUDIO == 1)
  t_telemetryData telemetryData; 
  uint8_t payload[243];

  audio_getData(&telemetryData);

  sensor_getAudioData(payload, sizeof(payload));
#else
#if (LORA_ENABLE == 1)
  lora_process();

  if ((e_dataState == e_dataStateSended) ||
      (e_dataState == e_dataStateSendFailed) ||
      (e_dataState == e_dataStateNotChange)) {
    e_dataState = e_dataStateStandby;

    gotoSleep();
  }

  if (e_dataState == e_dataStateQueued) {
    if ((startDataQueuedTime != 0) && (millis() > (startDataQueuedTime + 20000))) {
      // todo qos
      startDataQueuedTime = 0;
      e_dataState = e_dataStateSended; /* force go to sleep state */
    }
  }
#else
  sensor_getData();

  // delay(1000);

  // sensor_suspend();
  // delay(5000);

  if(t_ramRet.telemetryData.contentInfo.details.motionDetectionOrPowerOn)
    t_ramRet.dataCommon.lastSendMotionOrPowerTime = rtc_read();

  ramret_save(&t_ramRet);

  power_sleep(e_SLEEP_MODE_OFF, e_WAKEUP_TYPE_RTC, 120 /*seconde*/, WAKEUP_PIN);
#endif
#endif

  //display_mallinfo();
}

#if (LORA_ENABLE == 1)
/***************************************************************************************
 *
 *	\fn		static int32_t lora_sendDataCallback(uint8_t *payload, uint8_t payloadSize, uint8_t *p_sendSize)
 *	\brief
 *
 ***************************************************************************************/
static int32_t lora_sendDataCallback(uint8_t *payload, uint8_t payloadSize, uint8_t *p_sendSize) {
  uint16_t payloadTmp;
  int32_t ret;
  uint8_t i, sendSize = 0;

  if ((payload == NULL) || !payloadSize || (p_sendSize == NULL))
    return ERROR;

  ret = sensor_getData();

  if (ret != OK)
    return ret;

  // add content info first
  payload[sendSize++] = t_ramRet.telemetryData.contentInfo.data[0];
  payload[sendSize++] = t_ramRet.telemetryData.contentInfo.data[1];

  if (t_ramRet.telemetryData.contentInfo.details.baseInfo == TRUE) {
    // hardware id : hardware_id (12 bytes)
    memcpy(&payload[sendSize], (uint8_t *)STM32_UUID, 3 * sizeof(uint32_t));
    sendSize += (3 * sizeof(uint32_t));

    // tx interval : measurement_interval_min (1 byte)
#if (USE_EEPROM == 1)
    payload[sendSize++] = t_eeprom.sendFrequency;
#else
    payload[sendSize++] = t_ramRet.sendFrequency;
#endif

    // hw version : hardware_version (1 bytes)
    payload[sendSize++] = (uint8_t)HW_VERSION;

    // fw version : firmware_version (2 bytes)
    payload[sendSize++] = highByte((uint16_t)SW_REVISION);
    payload[sendSize++] = lowByte((uint16_t)SW_REVISION);

    // time device : time_device
    // payload[sendSize++] =
    // payload[sendSize++] =
    // payload[sendSize++] =
    // payload[sendSize++] =

    // total byte 17 + 4 (if time)
  }

  if (t_ramRet.telemetryData.contentInfo.details.boot == TRUE) {
    payload[sendSize++] = t_ramRet.dataCommon.boot;
  }

  if (t_ramRet.telemetryData.contentInfo.details.temperatureOutside == TRUE) {
    payloadTmp = t_ramRet.telemetryData.temperatureOutside * 100;
    payload[sendSize++] = highByte(payloadTmp);
    payload[sendSize++] = lowByte(payloadTmp);
  }

  if (t_ramRet.telemetryData.contentInfo.details.humidityOutside == TRUE) {
    payloadTmp = t_ramRet.telemetryData.humidityOutside * 100;
    payload[sendSize++] = highByte(payloadTmp);
    payload[sendSize++] = lowByte(payloadTmp);
  }

  if (t_ramRet.telemetryData.contentInfo.details.pressureOutside == TRUE) {
    payloadTmp = t_ramRet.telemetryData.pressureOutside; /* 100 exceed 16 bits encoding */
    payload[sendSize++] = highByte(payloadTmp);
    payload[sendSize++] = lowByte(payloadTmp);
  }

  if (t_ramRet.telemetryData.contentInfo.details.weight == TRUE) {
    payloadTmp = t_ramRet.telemetryData.weight * 100;
    payload[sendSize++] = highByte(payloadTmp);
    payload[sendSize++] = lowByte(payloadTmp);
  }

  if (t_ramRet.telemetryData.contentInfo.details.vbatt == TRUE) {
    payloadTmp = t_ramRet.telemetryData.vbatt;
    payload[sendSize++] = highByte(payloadTmp);
    payload[sendSize++] = lowByte(payloadTmp);

    payloadTmp = analog_getVBattPercent(t_ramRet.telemetryData.vbatt) * 100;
    payload[sendSize++] = highByte(payloadTmp);
    payload[sendSize++] = lowByte(payloadTmp);
  }

  if (t_ramRet.telemetryData.contentInfo.details.humidityInside == TRUE) {
    payloadTmp = t_ramRet.telemetryData.humidityInside * 100;
    payload[sendSize++] = highByte(payloadTmp);
    payload[sendSize++] = lowByte(payloadTmp);
  }

  if (t_ramRet.telemetryData.contentInfo.details.temperatureInside) {
    for (i = 0; i < t_ramRet.telemetryData.contentInfo.details.temperatureInsideCount; i++) {
      payloadTmp = t_ramRet.telemetryData.temperatureInside[i] * 100;
      payload[sendSize++] = highByte(payloadTmp);
      payload[sendSize++] = lowByte(payloadTmp);
    }
  }

  if (t_ramRet.telemetryData.contentInfo.details.custom == TRUE) {
  }

  if (t_ramRet.telemetryData.contentInfo.details.audio == TRUE) {
    uint8_t size = sensor_getAudioData(&payload[sendSize], payloadSize - sendSize);

    if (!size) {
      /*payload[sendSize++] = 0x00; // binOffset
      payload[sendSize++] = 0x00; // binOffset
      payload[sendSize++] = 0x00; // binSize
      payload[sendSize++] = 0x00; // binCount*/
      return ERROR;
    } else
      sendSize += size;
  }

  *p_sendSize = sendSize;

  return OK;
}

/***************************************************************************************
 *
 *	\fn		static void lora_eventCallback(e_LORA_EVENT e_event, void* pv_data)
 *	\brief
 *
 ***************************************************************************************/
static void lora_eventCallback(e_LORA_EVENT e_event, void *pv_data, uint32_t size) {
  switch (e_event) {
  case e_TX_RX_ACK:
    TRACE_CrLf("[LORA] received ack tx / rx");
    break;

  case e_RX_DATA: {
    uint8_t *pu8_data = (uint8_t *)pv_data;
    uint32_t i;

    if ((pu8_data == NULL) || !size)
      break;

    TRACE("[LORA] received %d bytes :", size);
    for (i = 0; i < size; i++) {
      TRACE(" %02x", pu8_data[i]);
    }
    TRACE_CrLf("");

    /* todo get audio config and store in flash (count, start,stop,gain,sampling frequency) */

    break;
  }

  case e_TX_DATA_QUEUED:
    TRACE_CrLf("[LORA] data queued (%d bytes)", size);

    startDataQueuedTime = millis();

    e_dataState = e_dataStateQueued;
    break;

  case e_TX_DONE:
    TRACE_CrLf("[LORA] data sended");

    if (t_ramRet.telemetryData.contentInfo.details.baseInfo == TRUE) {
      t_ramRet.dataCommon.baseInfoSended = TRUE;
      TRACE_CrLf("[LORA] base info sended");
    }

    if (e_dataState != e_dataStateStandby)
      e_dataState = e_dataStateSended;
    break;

  case e_DATA_NOT_CHANGED:
    TRACE_CrLf("[LORA] data not changed");

    e_dataState = e_dataStateNotChange;
    break;

  case e_SEND_FAILED:
    TRACE_CrLf("[LORA] send failed");
#if 0
      uint32_t now = rtc_read();

      //uint32_t lapse = now - t_ramRet.lastSendTime;

      if(lapse < (MIN_TO_SEC(t_ramRet.sendFrequency) - 1)) {
        TRACE_CrLf("[ERROR] send time lapse %d, timestamp %d, run %d", lapse, now, runTime);

        t_ramRet.forceNewJoining = TRUE;
        ramret_save(&t_ramRet);

        system_reset();
      }
#endif

    e_dataState = e_dataStateSendFailed;
    break;

  case e_RX_TIME: {
    if (pv_data == NULL)
      break;

    struct tm time_info;
    uint32_t *p_time = (uint32_t *)pv_data;
    uint32_t now = rtc_read();

    if(FALSE == rtc_isTsValid(*p_time)) {
      TRACE_CrLf("[LORA] not valid ts %d", *p_time);
      break;
    }

    _rtc_localtime(*p_time, &time_info, RTC_4_YEAR_LEAP_YEAR_SUPPORT);

    TRACE_CrLf("[LORA] utc time is: %02d:%02d:%02d %02d/%02d/%02d, ts %d", time_info.tm_hour,
               time_info.tm_min,
               time_info.tm_sec,
               time_info.tm_mday,
               time_info.tm_mon + 1,
               time_info.tm_year - 100,
               *p_time);

    if(time_lapse(now, *p_time) < 10) {
      TRACE_CrLf("[LORA] time offset < 10");
      
      t_ramRet.dataCommon.timeUpdated = TRUE;
      
      break;
    }  

    if(OK == rtc_write(*p_time)) {
      t_ramRet.dataCommon.timeUpdated = TRUE;
      t_ramRet.dataCommon.lastUpdateTime = *p_time;
    }

    // read and check if error set 0 ts !!! wait diag before implementation

    TRACE_CrLf("[DEBUG] start %d, write %d, end %d", now, *p_time, rtc_read());

    break;
  }
  }
}

#if (STANDBY_ENABLE == 0)
/***************************************************************************************
 *
 *	\fn		static void lora_wakeupCallback(void)
 *	\brief
 *
 ***************************************************************************************/
static void lora_wakeupCallback(void) {
  e_dataState = e_dataStateDefault;

  startTime = rtc_read();

  if (power_isPoweredOn() == FALSE)
    TRACE_CrLf("################");

  TRACE_CrLf("[RTC] send data, timestamp: %d, sleep time %d", startTime, startTime - t_ramRet.lastSendTime);

  if (t_ramRet.audioSettings.sendData == FALSE) {
    if (sensor_setup(&t_ramRet, &t_ramRet, FLAG_ALL_WITHOUT_AUDIO) != OK) {
      // todo qos
    }
  } else {
    if (sensor_setup(&t_ramRet, &t_ramRet, FLAG_AUDIO_INFO) != OK) {
      // todo qos
    }
  }
}
#endif

/***************************************************************************************
 *
 *	\fn		static void gotoSleep(void)
 *	\brief
 *
 ***************************************************************************************/
static void gotoSleep(void) {
  uint32_t now = rtc_read();
  uint32_t runTime = constrain(now - startTime, 0, 0xffffffff);
  uint32_t sleepTime = 60;
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

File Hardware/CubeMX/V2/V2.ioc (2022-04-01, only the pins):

Mcu.UserName=STM32F411CEUx
PA0-WKUP.GPIO_Label=WAKEUP
PA0-WKUP.Signal=SYS_WKUP
PA1.GPIO_Label=I2S_SD/MIC_ANA
PA1.Signal=I2S4_SD
PA10.Signal=USART1_RX
PA11.GPIO_Label=USB_DN
PA11.Signal=USB_OTG_FS_DM
PA12.GPIO_Label=USB_DP
PA12.Signal=USB_OTG_FS_DP
PA13.GPIO_Label=SW_DIO
PA13.Signal=SYS_JTMS-SWDIO
PA14.GPIO_Label=SW_CLK
PA14.Signal=SYS_JTCK-SWCLK
PA15.GPIO_Label=PWR_OFF
PA15.Signal=GPIO_Output
PA2.GPIO_Label=BTN_TARE/EN_AVBATT 
PA2.Signal=GPIO_Input
PA3.GPIO_Label=FLASH_NSS
PA3.Signal=GPIO_Output
PA4.GPIO_Label=LORA_NSS
PA4.Signal=SPI1_NSS
PA5.Signal=SPI1_SCK
PA6.Signal=SPI1_MISO
PA7.Signal=SPI1_MOSI
PA8.GPIO_Label=MCO/LED_INFO
PA8.Signal=RCC_MCO_1
PA9.Signal=USART1_TX
PB0.GPIO_Label=LORA_RST
PB0.Signal=GPIO_Output
PB1.GPIO_Label=LORA_DIO0
PB1.Signal=GPIO_Input
PB10.GPIO_Label=LORA_DIO2
PB10.Signal=GPIO_Input
PB12.GPIO_Label=I2S_WS
PB12.Signal=I2S4_WS
PB13.GPIO_Label=I2S_CK/MIC_GAIN
PB13.Signal=I2S4_CK
PB14.GPIO_Label=TRACE_EN
PB14.Signal=GPIO_Input
PB15.GPIO_Label=SCALE_TYPE
PB15.Signal=GPIO_Input
PB2.GPIO_Label=LORA_DIO1
PB2.Signal=GPIO_Input
PB3.GPIO_Label=EN_3V3_INT
PB3.Signal=GPIO_Output
PB4.GPIO_Label=EN_3V3_EXT
PB4.Signal=GPIO_Output
PB5.GPIO_Label=HX711_RATE
PB5.Signal=GPIO_Output
PB6.GPIO_Label=HX711_DT
PB6.Signal=GPIO_Input
PB7.GPIO_Label=HX711_CK
PB7.Signal=GPIO_Output
PB8.Signal=I2C1_SCL
PB9.Signal=I2C1_SDA
PC13-ANTI_TAMP.GPIO_Label=WDG_RELOAD
PC13-ANTI_TAMP.Signal=GPIO_Output
PC14-OSC32_IN.Signal=RCC_OSC32_IN
PC15-OSC32_OUT.Signal=RCC_OSC32_OUT

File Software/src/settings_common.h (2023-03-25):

/************************************************************************************//**
 *
 *	\file		settings_common.h
 *
 *	\brief
 *
 *	\date		25 mar. 2023
 *
 *	\author		ecoapi
 *
 ***************************************************************************************/

#ifndef __SETTINGS_COMMON_H
#define __SETTINGS_COMMON_H

/***************************************************************************************/
/*	Includes																		
/***************************************************************************************/
#include <stdint.h>
#include "board.h"

#ifdef __cplusplus
extern "C" {
#endif

/***************************************************************************************/
/* Define
/***************************************************************************************/
#define MAX_TEMPERATURE_INSIDE 2
#define LORA_DEFAULT_MAX_WAIT_DOWNLINK_CYCLE 4  // max value 7 (3 bits)

#define AUDIO_DEFAULT_BIN_OFFSET 13 // 13 * 3.789062Hz = 49.26Hz first not audible
#define AUDIO_DEFAULT_BIN_SIZE 13
#define AUDIO_MAX_BINS 20
#define AUDIO_DEFAULT_MAX_SEND_DATA_CYCLE 2 // max value 7 (3 bits)
#define AUDIO_SEND_DATA_OFFSET 1 // minimum minutes for duty cyle ttn
#define AUDIO_DEFAULT_SAMPLING_FREQUENCY 1

#define DEFAULT_SEND_FREQUENCY 15 // minutes
#define DEFAULT_UPDATE_TIME_PERIOD 86400 // seconds

#define DEFAULT_MOTION_DETECT_PERIOD  60 // seconds min ttn between two frame
#define DEFAULT_STANDBY_MOTION_DETECT_TIMEOUT 30 // seconds

#define MIN_SLEEP_PERIOD 60 // seconds
#define MAX_SLEEP_PERIOD 86400 // seconds

/***************************************************************************************/
/* Typedef                                                                        
/***************************************************************************************/
typedef struct t_SensorPresence_ {
  uint16_t sht3x:1; /* i2c */ 
  uint16_t si7021:1; /* i2c */
  uint16_t as6200:1; /* i2c */
  uint16_t bmpxxx:1; /* i2c (check if same address) */
  uint16_t bmexxx:1; /* i2c (check if same address) */
  uint16_t my_custom_sensor:1;  /* i2c create slave with register 0x00 = n telemetry, 0x01 data type 1, 0x02 data 1, 0x03 data type n, 0x04 data n ... */
  uint16_t audio_enable:1; /* false : no audio used */

  uint16_t audio_type:1; /* true : i2s, false : adc */
  uint16_t hx711:1; /* bus check */
  uint16_t ads12xx:1; /* bus check */
  uint16_t nau7802:1; /* bus check */
  uint16_t reserved1:5;
} t_SensorPresence;

typedef union t_ContentInformation_ {
  struct {    
    uint8_t baseInfo:1;
    uint8_t boot:1;
    uint8_t temperatureOutside:1;
    uint8_t humidityOutside:1;
    uint8_t pressureOutside:1;
    uint8_t weight:1;
    uint8_t vbatt:1;
    uint8_t humidityInside:1;
    
    uint8_t audio:1;
    uint8_t custom:1;
    uint8_t temperatureInside:1;
    uint8_t temperatureInsideCount:3;
    uint8_t scaleType:1;
    uint8_t motionDetectionOrPowerOn:1;
  } details;
  uint8_t data[2];  
} t_ContentInformation;
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

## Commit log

2021-04-09 Add V1.0 hardware files (kicad project)
    [EEE-FK0J102GP.stp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]
2021-04-09 Add pdf schematic
2021-10-29 Add lora, adc, bmp180, trace, 1wire and hx711
    [stm32f4x.cfg]
2021-11-02 Fix illegall access and add wdg
    [lora.cpp, main.cpp, sensor.cpp]
2021-11-05 Fix power consumption 120µA for the moment (regulator on blackpill board)
    [stm32f4x.cfg]
2021-12-03 Add fft from audio ana mic (max9814) and add sht3x sensor and add dwonlink adr support
2021-12-04 Remove fft outpu noise
    [audio.cpp]
2022-01-07 Add V2 schematic
    [1042.step, 1N4148WT.step, 24LC02B_SN.step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]
2022-01-07 Remove V1 Hardware info
    [1042.step, 1N4148WT.step, 24LC02B_SN.step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]
2022-01-26 Add pcb route and ground plane
    [614105150721.stp, ABS07-120-32.768KHZ-T.step, BSS138.step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]
2022-02-16 Fix drc error
    [EcoApi_pcb.kicad_pcb, MF-FSMF050X-2.stp, TPS63900DSKR.stp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]
2022-02-17 Add text on pcb front side
    [EcoApi_pcb.kicad_pcb]
2022-03-09 Update pcb to v2.1 (Add ldo)
    [EcoApi_pcb.kicad_pcb, MSS-102559-14A-D.step, NCP161ASN330T1G.stp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]
2022-03-24 Add Gerber files, Bom, Jlcpcb LCSC parts ref, some optimizations
    [BSS84AK,215.stp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]
2022-04-01 Fix JLCPCB assembly issues, Add reverse battery protection, Define Correct crystal capa, Add Layer number and fiducial, and some quicq fix
    [BAT46W-7-F.stp, BAT46WH,115.stp, BSS138PW,115.stp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]
2022-04-01 Add bom compatible with JLCPCB SMT assembly (LCSC refs), Add pick and place file with components rotation fixed
    [EcoApi_pcb_bom_bot.csv, EcoApi_pcb_bom_top.csv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]
2022-04-01 Update README.md
    Add link to JlcPcb tips for kicad
2023-01-29 Debug some features on hardware
    [cpu.sch, other.sch, peripheral.sch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]
2023-01-30 Fix motion detection, validation done for usb solar charger
    [power.sch]
2023-02-15 Fix rtc write time, fix hx711 rate, Add offset for vbatt, start i2s dma mic
    [other.sch, power.sch]
2023-03-01 Fix i2s and usb cdc
    [audio.cpp, audio_adc.cpp, audio_i2s.cpp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]
2023-03-02 Filter low frequency for I2S mic and scale fft result to u16
2023-03-03 Add mic auto-detect, add low cut frequency for i2s, add waiting time for vbatt read
2023-03-19 Fix rtc alarm lock 23:59 -> 00:xx, saturday to sunday
    [main.cpp, power.cpp, rtc_external.cpp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]
2023-03-25 Add eeprom usage for fixed settings
    [hx711.cpp, lora.cpp, main.cpp]

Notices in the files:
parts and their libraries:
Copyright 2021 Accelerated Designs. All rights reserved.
